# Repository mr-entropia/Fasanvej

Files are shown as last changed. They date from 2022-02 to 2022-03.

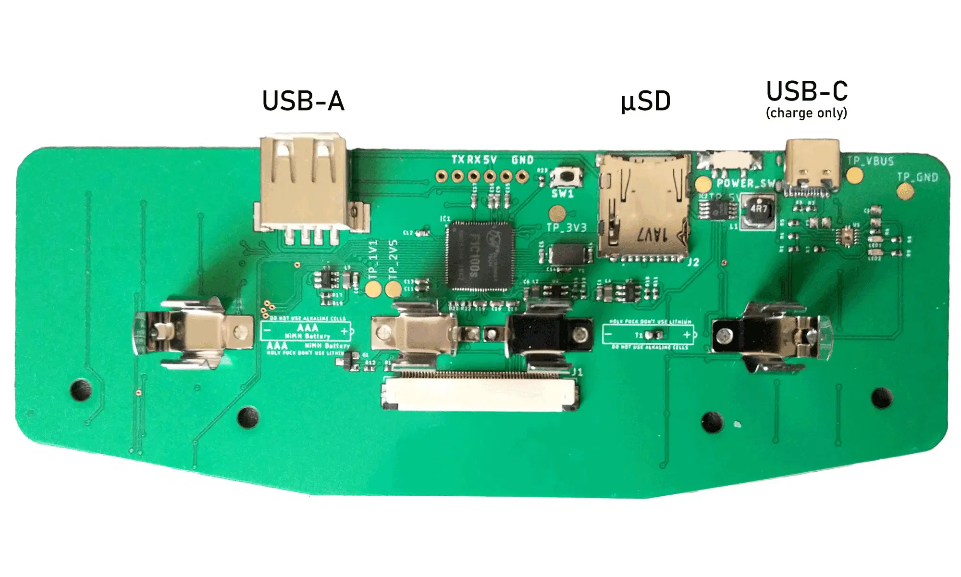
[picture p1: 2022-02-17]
Reference material/Allwinner-FC100s-minimal-viable-computer-board.webp

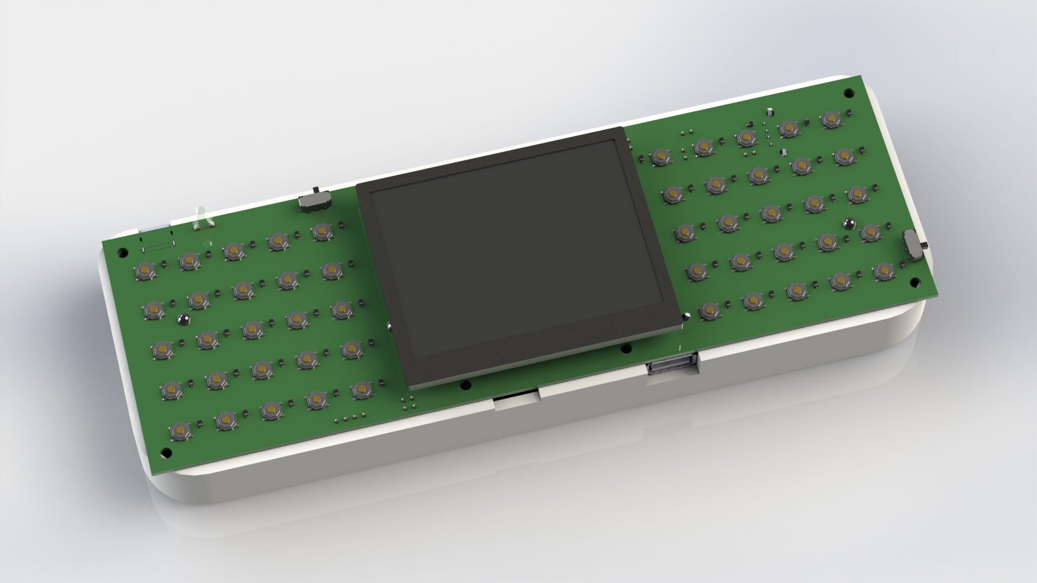
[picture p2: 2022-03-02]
render1_without_top.jpg

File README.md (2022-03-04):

# Fasanvej
A hand-held Linux computer, inspired by Brian Benchoff's similar project

## Features
- Allwinner F1C200s SoC, an ARM926EJ-S running at 500 MHz
- 64 MB DDR DRAM, embedded in the SoC
- 3.2" TFT LCD, 320x240 resolution
- QWERTY keyboard (implemented using a SAMD21 MCU, connects via USB)
- Game mode switch which alters key mapping
- USB hub with one external USB A connector
- Internal USB A type connector for a miniature WiFi adapter
- Mono speaker
- microSD slot
- SPI NOR FLASH
- Powered by 2P1S 18650 li-ion battery
- Built-in charger using a USB C type connector
- High efficiency DC-DC converters to power everything

## Task list
- [x] Finalize schematics
- [x] Place components on PCB
- [ ] Route PCB
- [x] Design a 3D-printable enclosure
- [ ] Source parts
- [ ] Build prototype
- [ ] Make software work
- [ ] Play DOOM

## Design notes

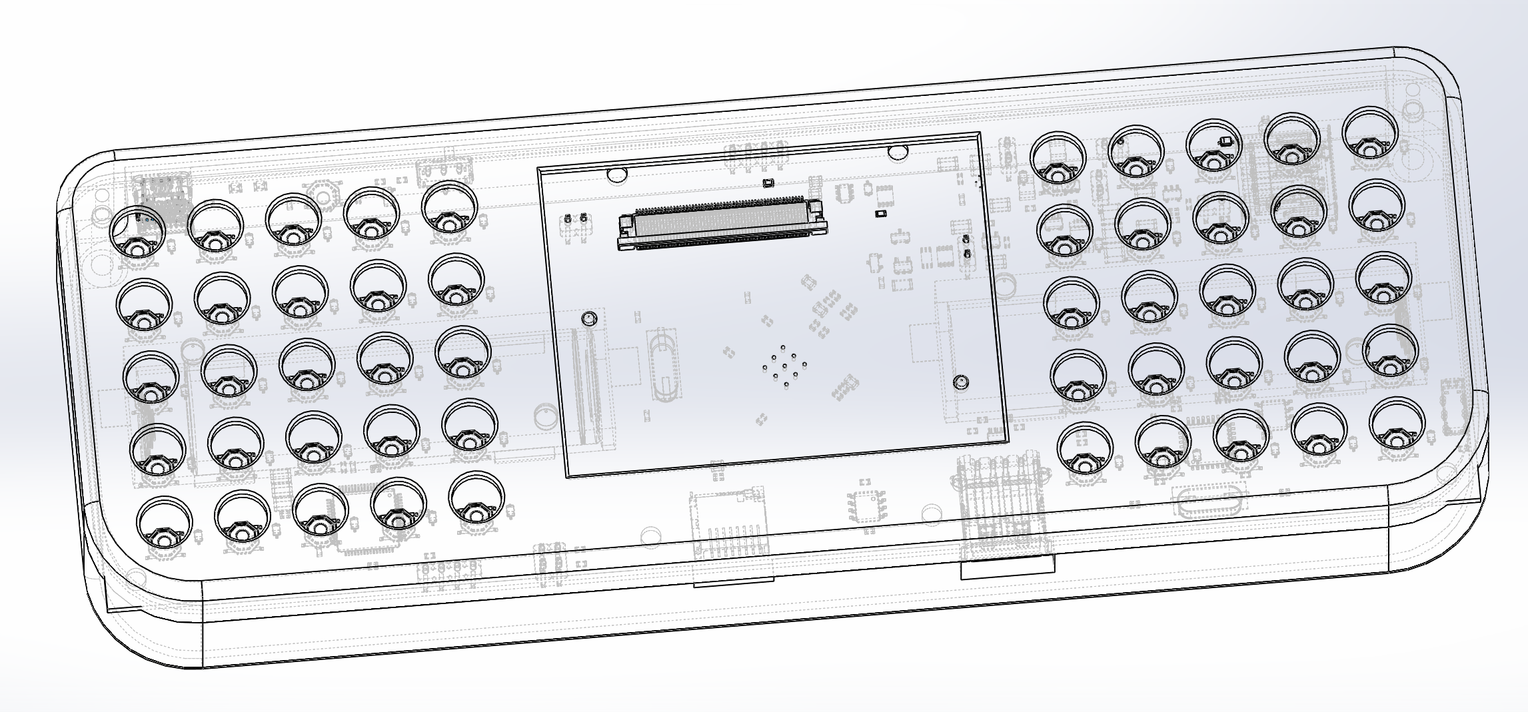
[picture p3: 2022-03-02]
Mech preview.png

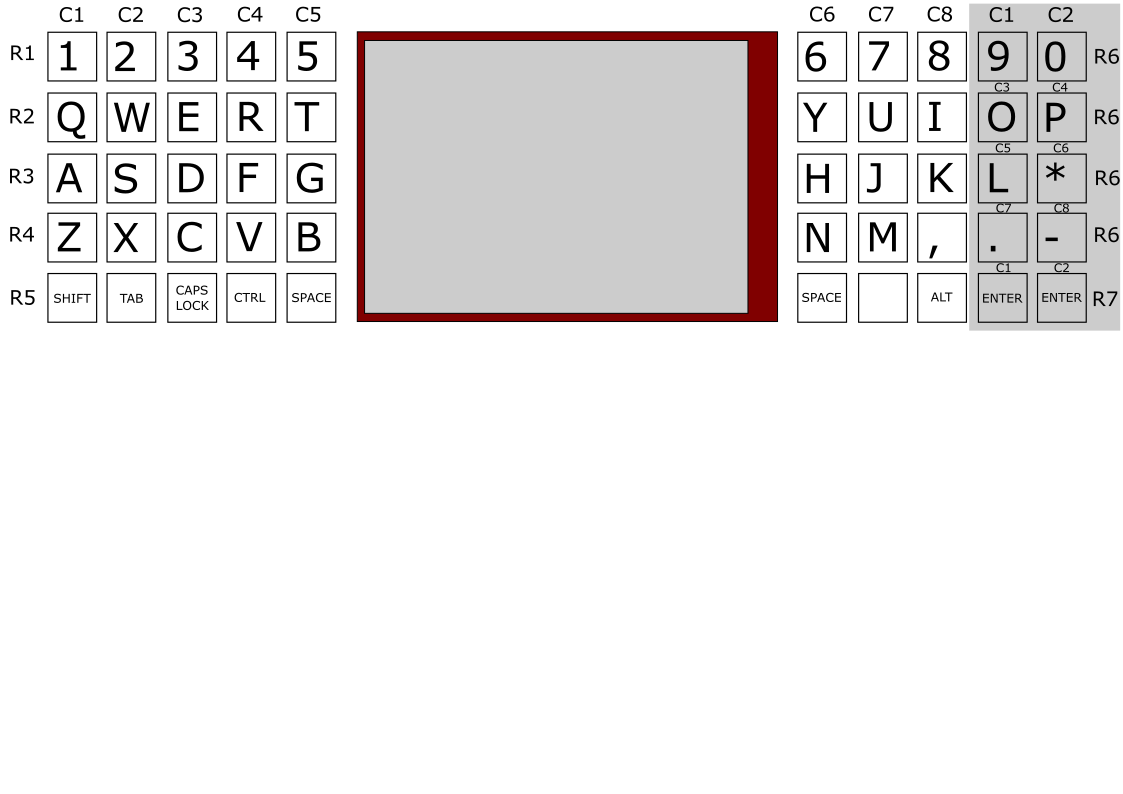
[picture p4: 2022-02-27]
Keymap.png

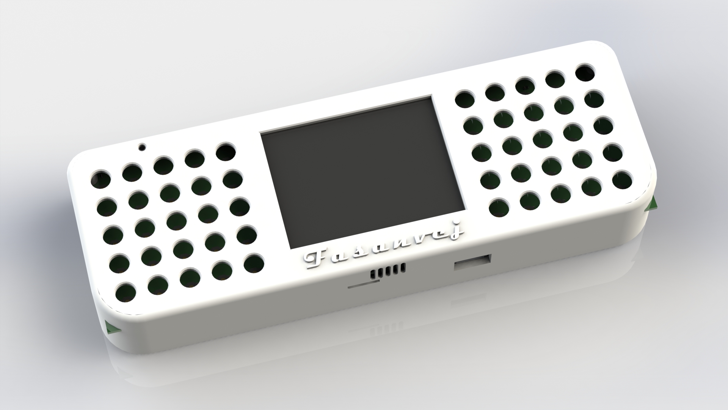
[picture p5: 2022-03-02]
render1.jpg

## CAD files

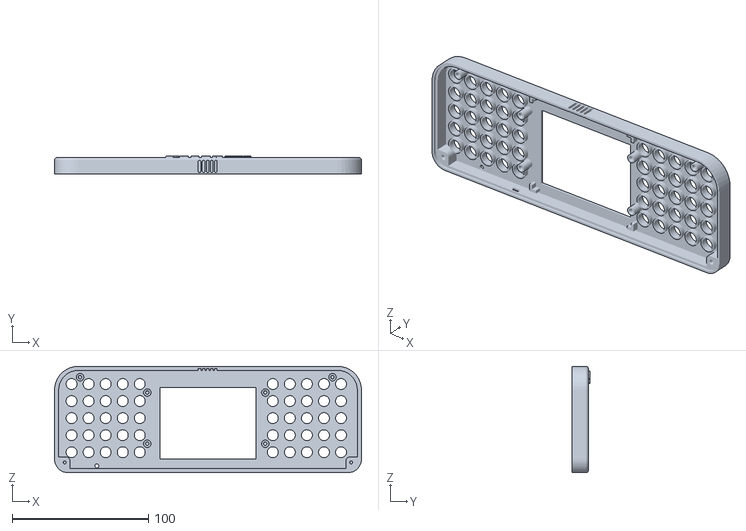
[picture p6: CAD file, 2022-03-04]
Mechanical/Case top.STL
225.0 x 13.0 x 78.0

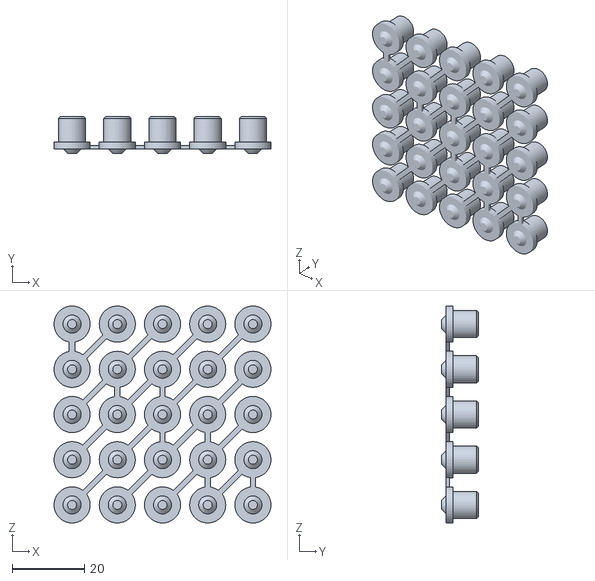
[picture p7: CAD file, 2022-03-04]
Mechanical/5x5 keymap.STL
60.0 x 10.2 x 60.0

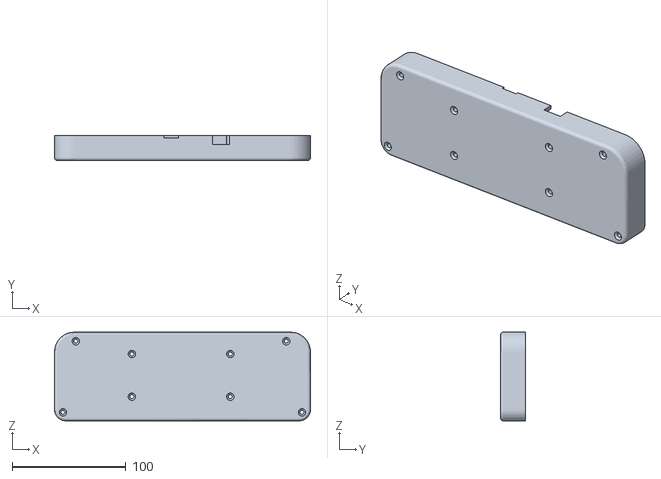
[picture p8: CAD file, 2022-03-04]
Mechanical/Case bottom.STL
225.0 x 22.0 x 78.0

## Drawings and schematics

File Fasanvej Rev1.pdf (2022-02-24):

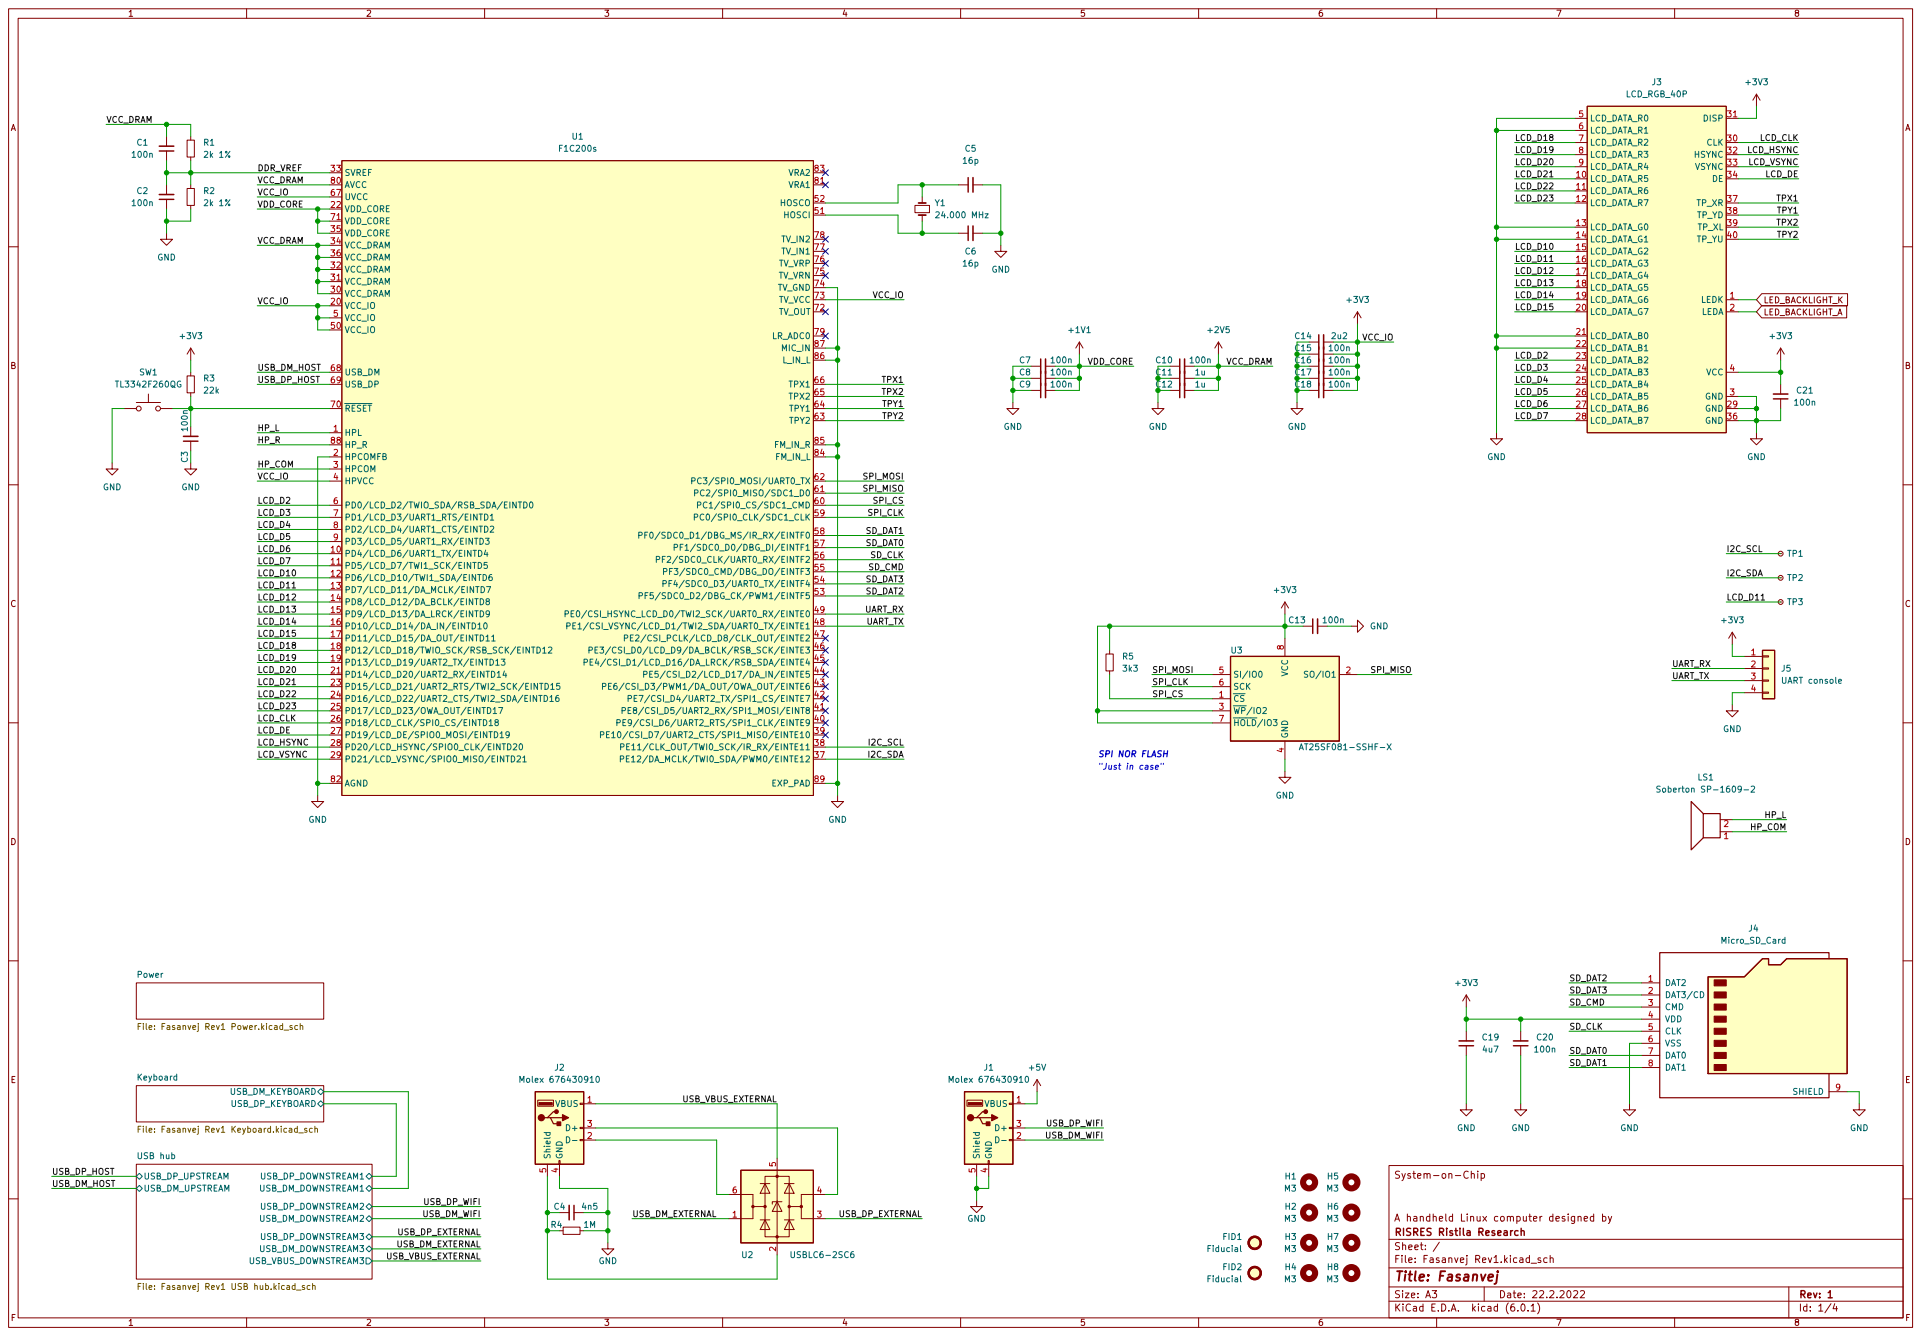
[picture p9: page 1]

4 SI/IO0 5 SCK 6 ~{HOLD}/IO3 7 VCC

"Just in case" SPI NOR FLASH

USB_DP_DOWNSTREAM3 USB_DP_DOWNSTREAM1 USB_DM_DOWNSTREAM1 USB_DM_DOWNSTREAM2 USB_DP_DOWNSTREAM2 USB_DM_DOWNSTREAM3 USB_VBUS_DOWNSTREAM3 USB hub File: Fasanvej Rev1 USB hub.kicad_sch Power File: Fasanvej Rev1 Power.kicad_sch

File: Fasanvej Rev1.kicad_sch Sheet: / RISRES Ristila Research A handheld Linux computer designed by

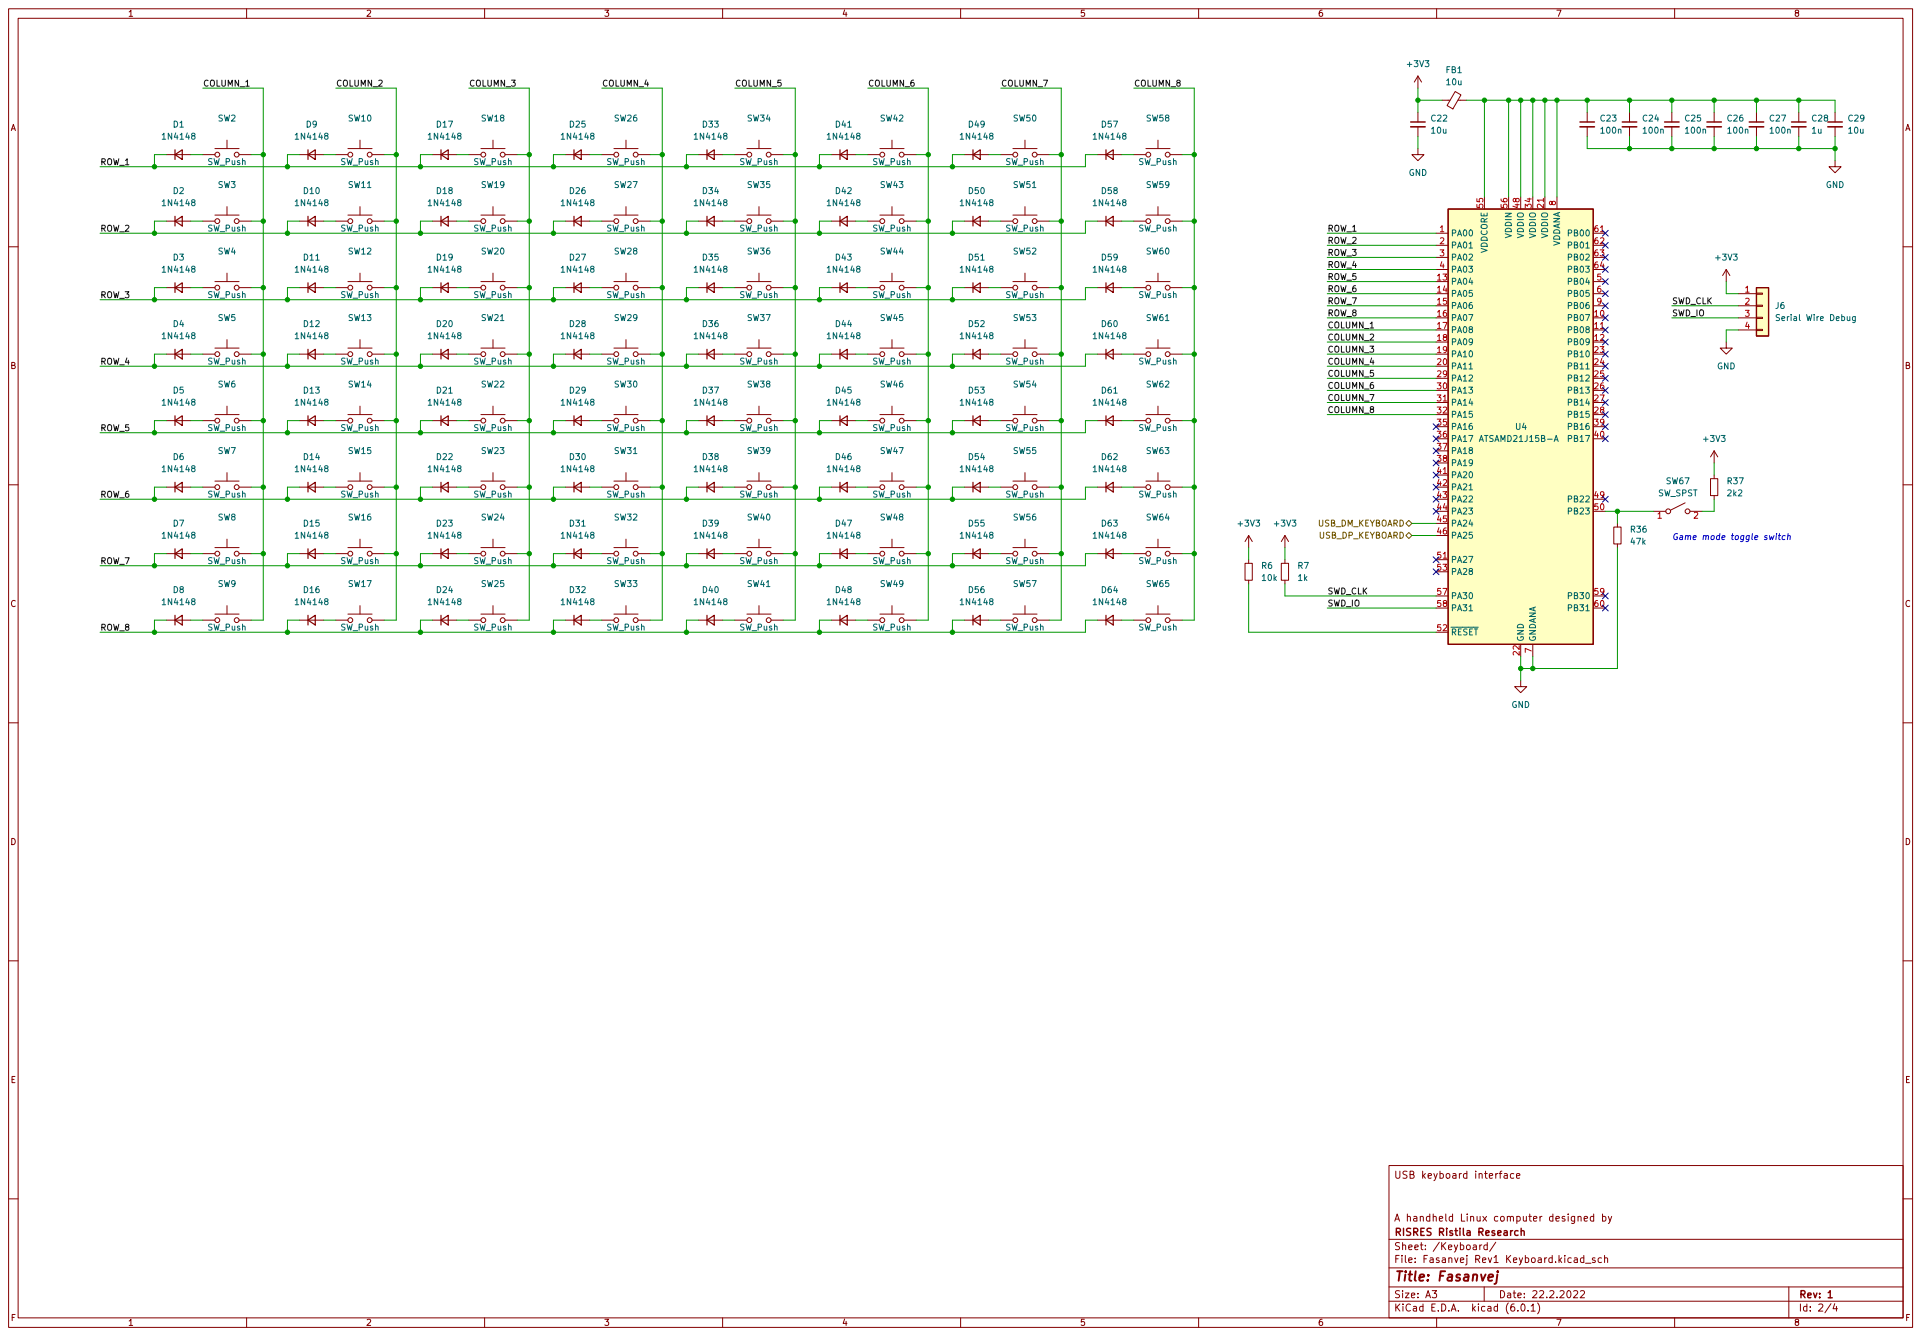
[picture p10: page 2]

Sheet: /Keyboard/ RISRES Ristila Research A handheld Linux computer designed by

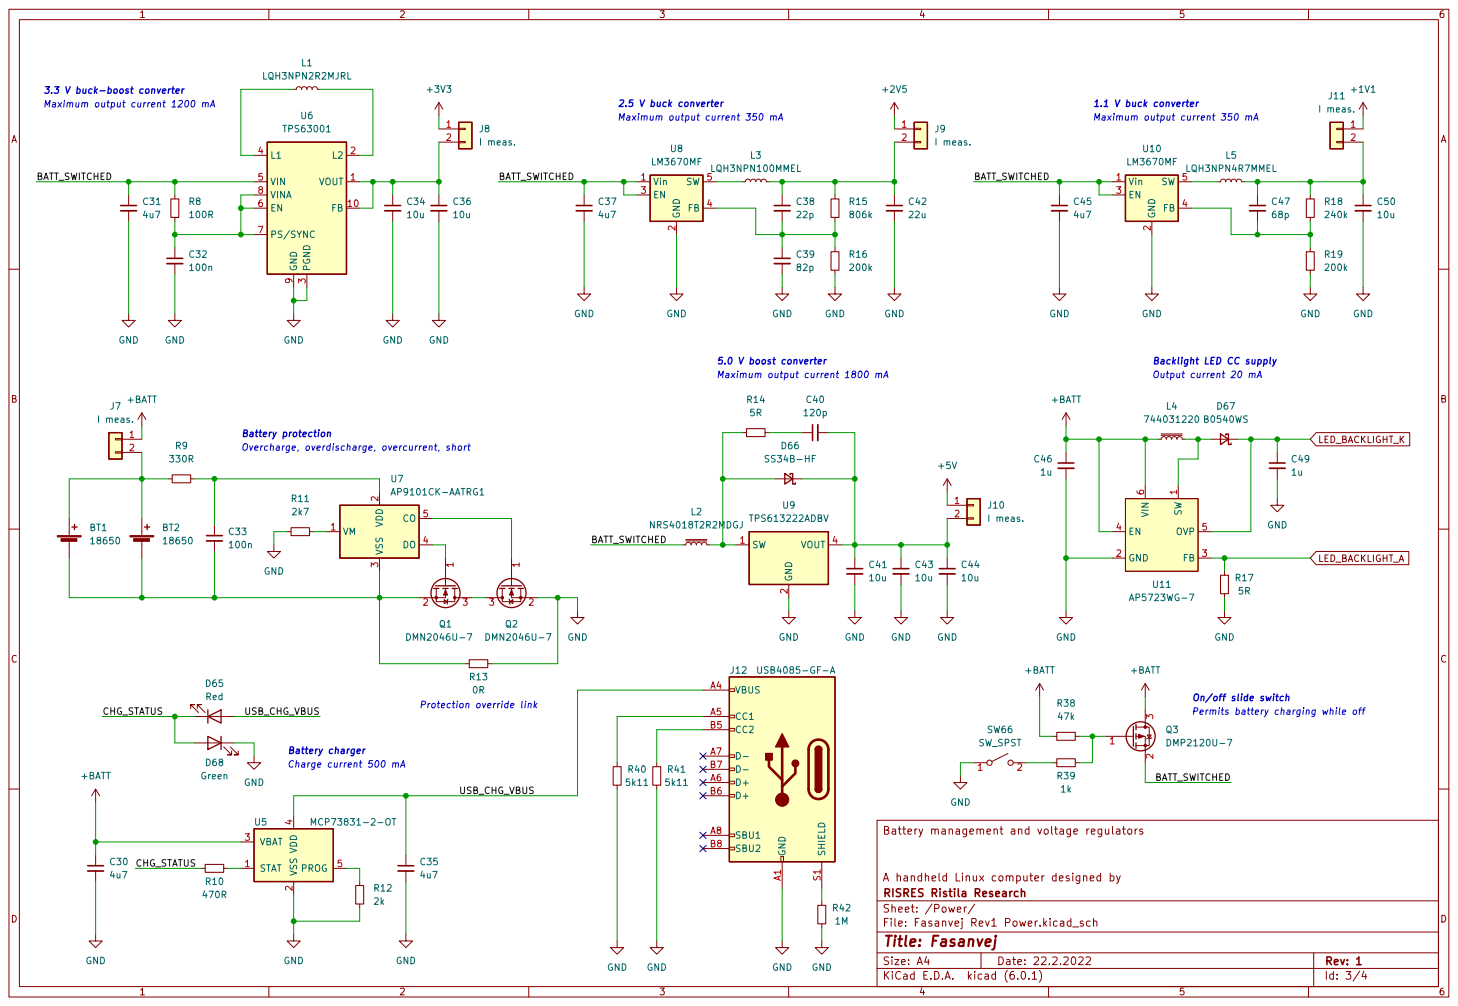
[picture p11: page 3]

Maximum output current 1200 mA

1.1 V buck converter On/off slide switch Permits battery charging while off
Maximum output current 350 mA

2.5 V buck converter

5.0 V boost converter Maximum output current 1800 mA

Backlight LED CC supply
Output current 20 mA

Battery protection
Overcharge, overdischarge, overcurrent, short

1 GND 2 FB 3 EN 4 OVP 5 VIN

Battery management and voltage regulators GND

File: Fasanvej Rev1 Power.kicad_sch Sheet: /Power/ RISRES Ristila Research A handheld Linux computer designed by

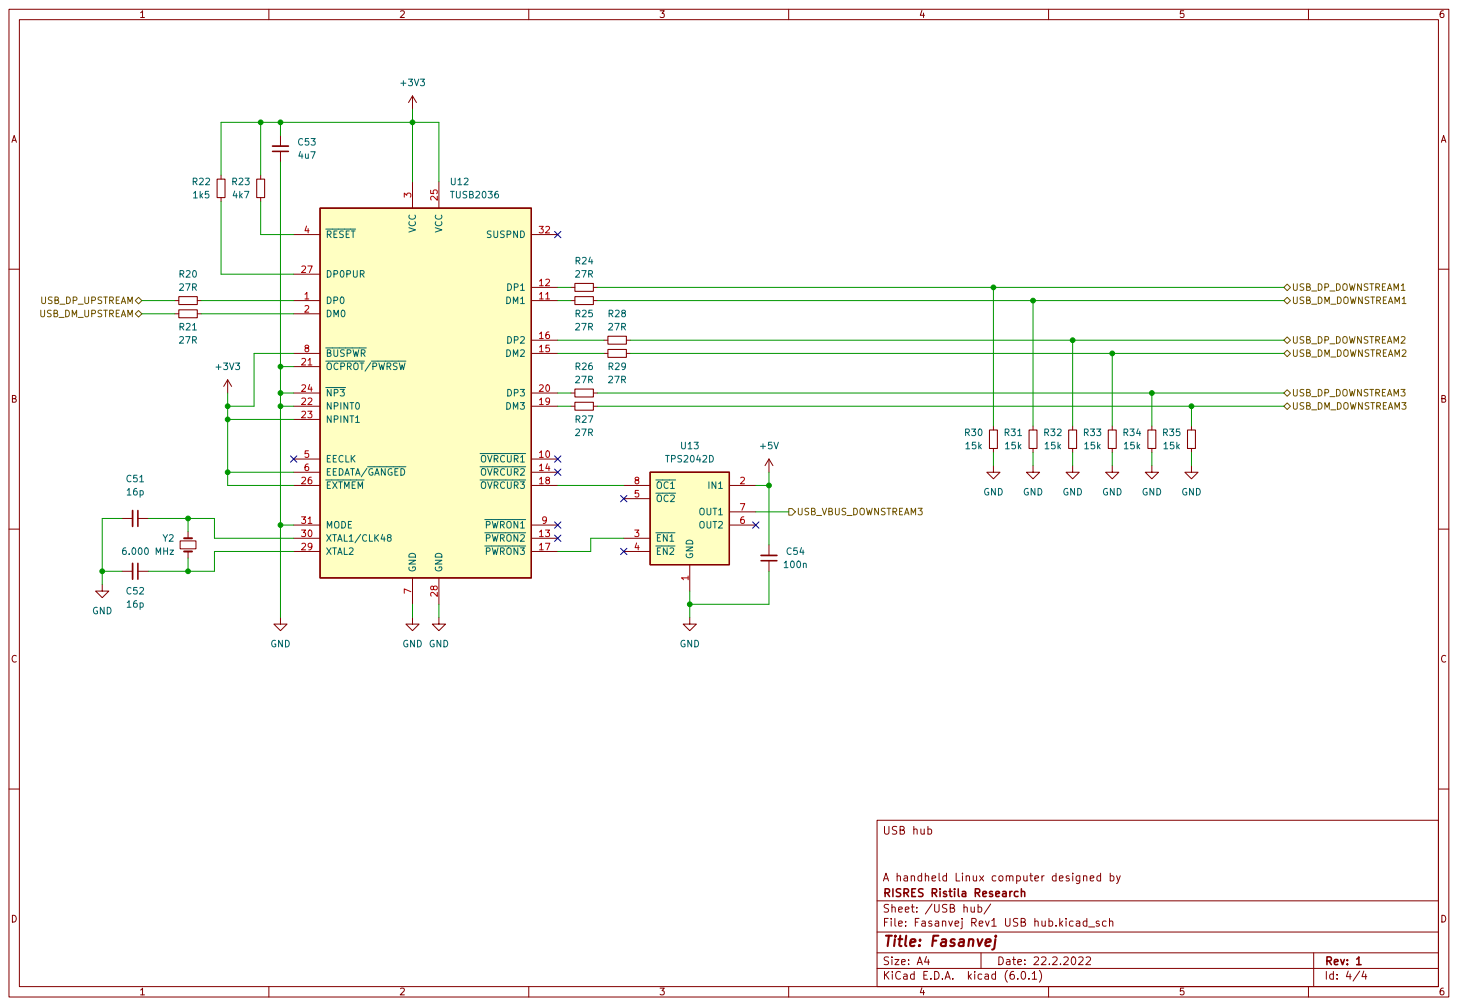
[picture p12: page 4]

3 XTAL1/CLK48 30 MODE 31 SUSPND 32 ~{RESET} 4 EECLK 5 EEDATA/~{GANGED} 6 GND

File: Fasanvej Rev1 USB hub.kicad_sch Sheet: /USB hub/ RISRES Ristila Research A handheld Linux computer designed by USB hub GND

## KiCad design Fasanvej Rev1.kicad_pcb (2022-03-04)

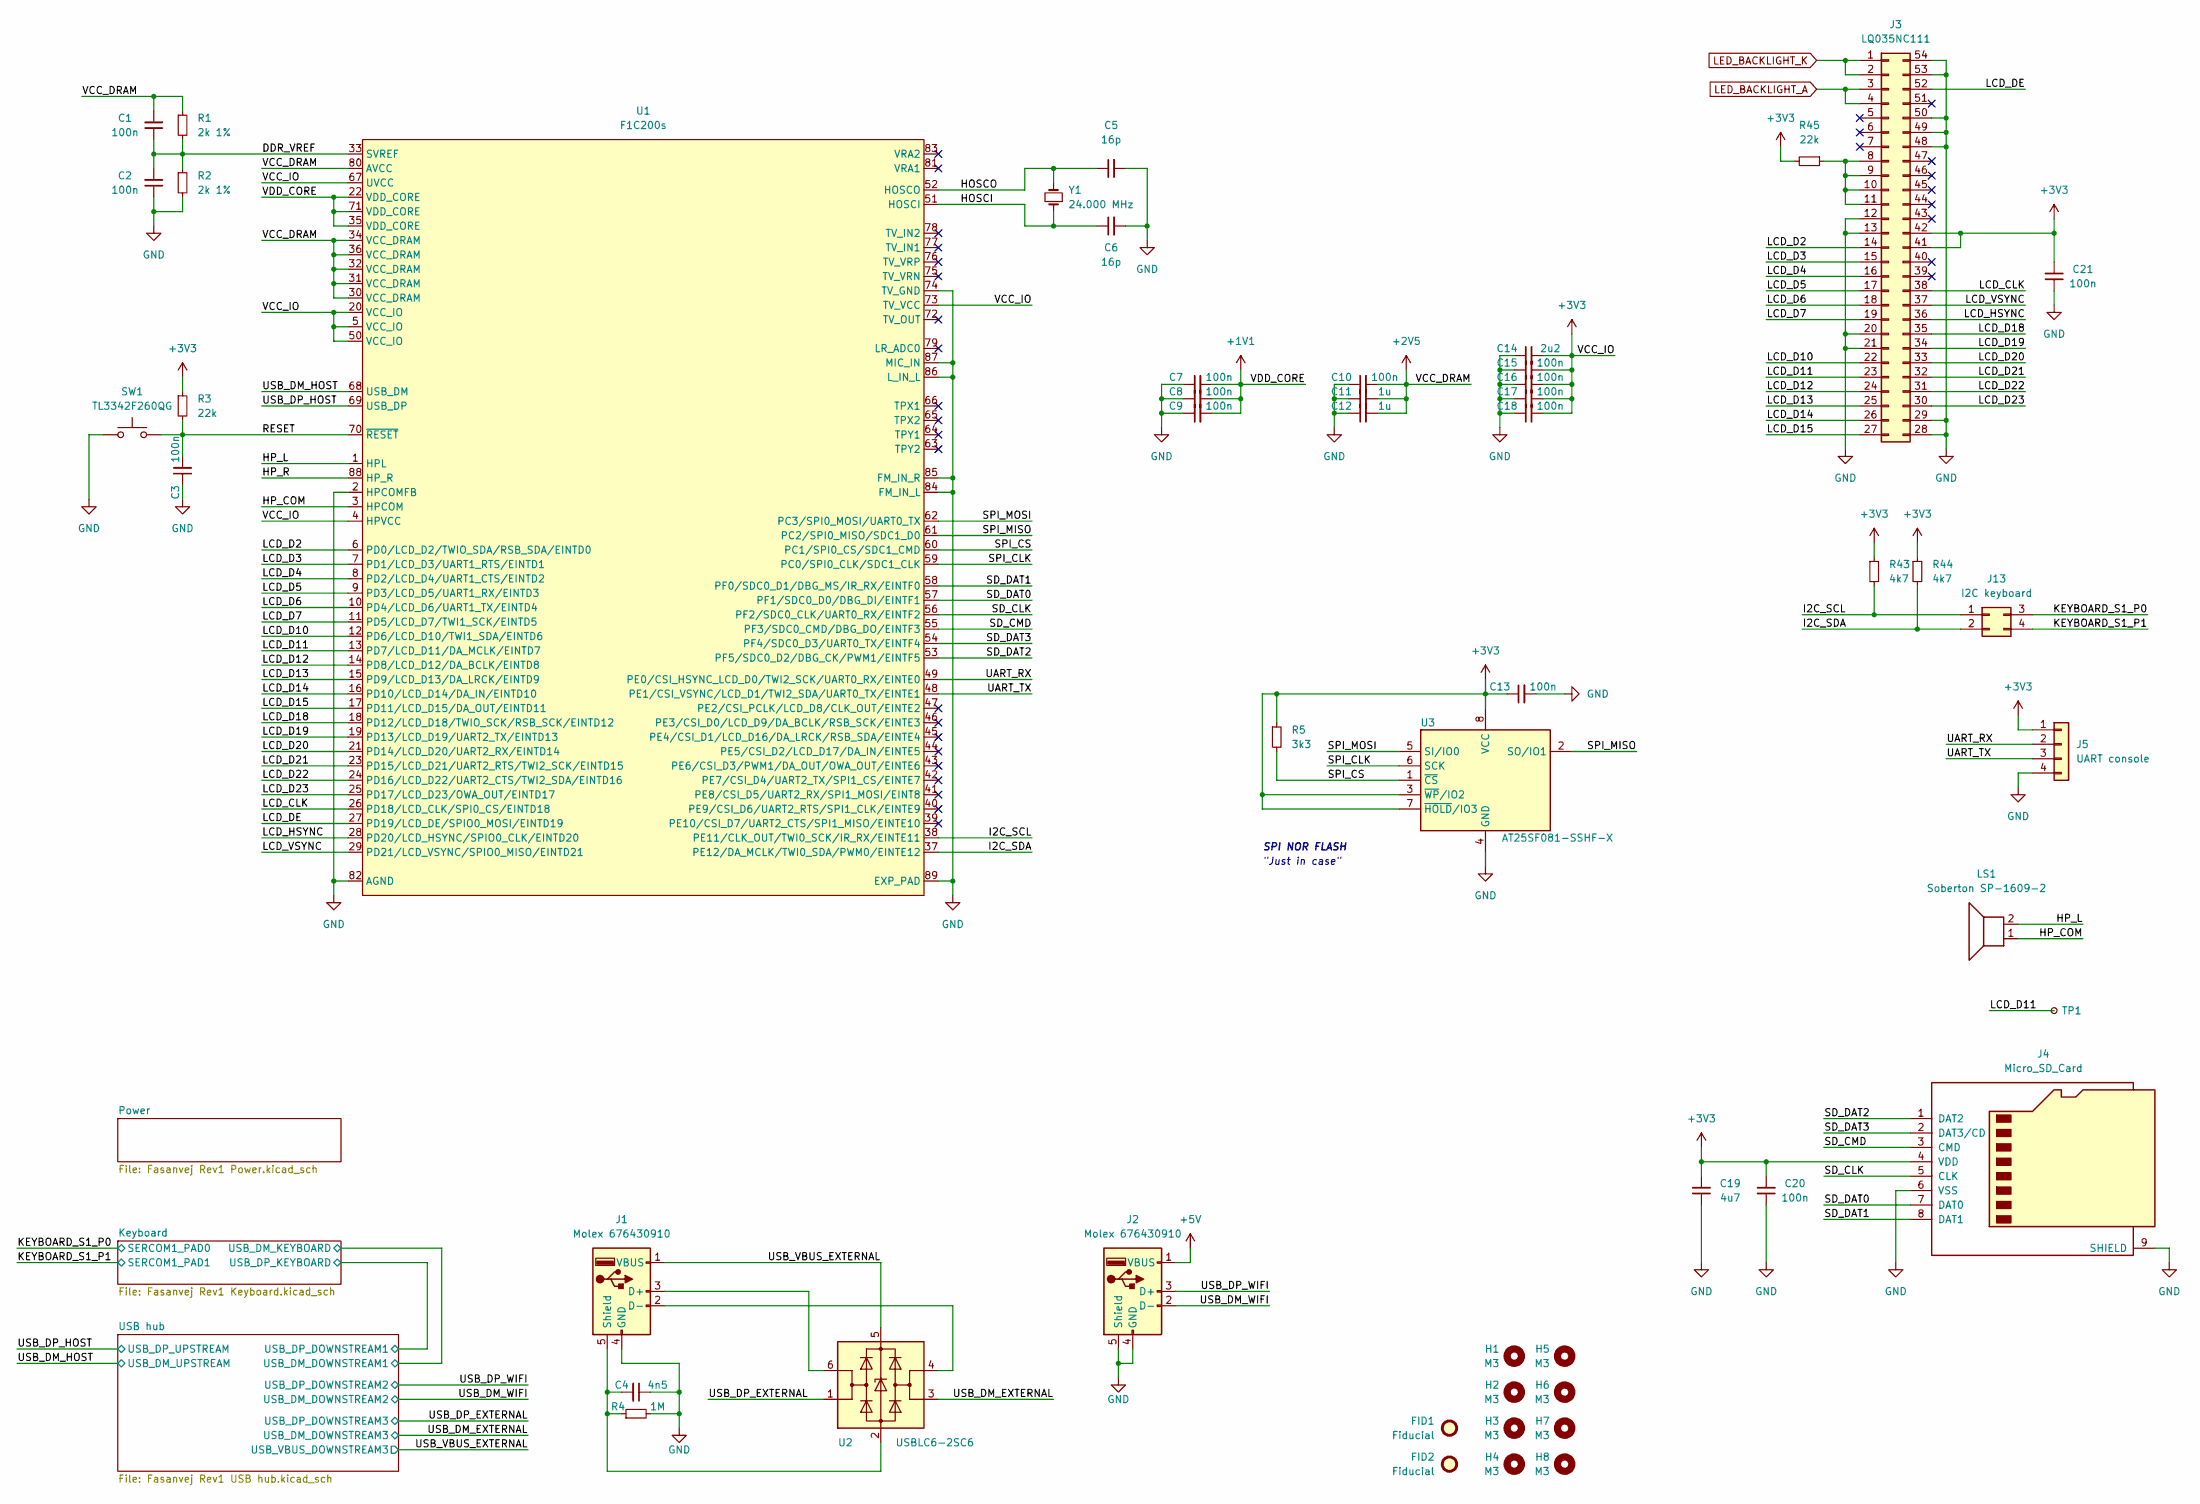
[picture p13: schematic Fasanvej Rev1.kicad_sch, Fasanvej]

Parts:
C1, C2, C3, C7, C8, C9, C10, C13, C15, C16, C17, C18, C20, C21: 100n; C_0603_1608Metric_Pad1.08x0.95mm_HandSolder
C4: 4n5; C_0603_1608Metric_Pad1.08x0.95mm_HandSolder
C5, C6: 16p; C_0603_1608Metric_Pad1.08x0.95mm_HandSolder
C11, C12: 1u; C_0805_2012Metric_Pad1.18x1.45mm_HandSolder
C14: 2u2; C_0805_2012Metric_Pad1.18x1.45mm_HandSolder
C19: 4u7; C_0805_2012Metric_Pad1.18x1.45mm_HandSolder
FID1, FID2: Fiducial; Fiducial_1.5mm_Mask3mm
H1, H2, H3, H4, H5, H6, H7, H8: M3; MountingHole_3.2mm_M3
J1, J2: Molex 676430910; USB_A_Molex_67643_Horizontal
J3: LQ035NC111; FFC2B22-54-T
J4: Micro_SD_Card; microSD_HC_Hirose_DM3D-SF
J5: UART console; PinHeader_1x04_P2.54mm_Vertical
J13: I2C keyboard; PinHeader_2x02_P2.54mm_Vertical
LS1: Soberton SP-1609-2; PinHeader_1x02_P2.54mm_Vertical
R1, R2: 2k 1%; R_0603_1608Metric_Pad0.98x0.95mm_HandSolder
R3, R45: 22k; R_0603_1608Metric_Pad0.98x0.95mm_HandSolder
R4: 1M; R_0603_1608Metric_Pad0.98x0.95mm_HandSolder
R5: 3k3; R_0603_1608Metric_Pad0.98x0.95mm_HandSolder
R43, R44: 4k7; R_0603_1608Metric_Pad0.98x0.95mm_HandSolder
SW1: TL3342F260QG; SW_SPST_TL3342
TP1: TestPoint_Small; TestPoint_Pad_D2.5mm
U1: F1C200s; QFN-88_EP_10x10_Pitch0.4mm
U2: USBLC6-2SC6; SOT-23-6
U3: AT25SF081-SSHF-X; SOIC-8_3.9x4.9mm_P1.27mm
Y1: 24.000 MHz; Crystal_SMD_HC49-SD_HandSoldering

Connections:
+1V1: C7.2, C8.2, C9.2, U1.22 (VDD_CORE), U1.35 (VDD_CORE), U1.71 (VDD_CORE); also elsewhere on the board
+2V5: C1.2, C10.2, C11.2, C12.2, R1.1, U1.30 (VCC_DRAM), U1.31 (VCC_DRAM), U1.32 (VCC_DRAM), U1.34 (VCC_DRAM), U1.36 (VCC_DRAM), U1.80 (AVCC); also elsewhere on the board
+3V3: C13.1, C14.2, C15.2, C16.2, C17.2, C18.2, C19.2, C20.2, C21.2, J3.41, J3.42, J4.4 (VDD), J5.1, R3.1, R5.1, R43.1, R44.1, R45.2, U1.4 (HPVCC), U1.5 (VCC_IO), U1.20 (VCC_IO), U1.50 (VCC_IO), U1.67 (UVCC), U1.73 (TV_VCC), U3.3 (~WP/IO2), U3.7 (~HOLD/IO3), U3.8 (VCC); also elsewhere on the board
+5V: J2.1 (VBUS); also elsewhere on the board
/DDR_VREF: C1.1, C2.2, R1.2, R2.1, U1.33 (SVREF)
/HOSCI: C6.1, U1.51 (HOSCI), Y1.1
/HOSCO: C5.1, U1.52 (HOSCO), Y1.2
/HP_COM: LS1.1, U1.3 (HPCOM)
/HP_L: LS1.2, U1.1 (HPL)
/HP_R: U1.88 (HP_R)
/I2C_SCL: J13.1, R43.2, U1.38 (PE11/CLK_OUT/TWI0_SCK/IR_RX/EINTE11)
/I2C_SDA: J13.2, R44.2, U1.37 (PE12/DA_MCLK/TWI0_SDA/PWM0/EINTE12)
/KEYBOARD_S1_P0: J13.3; also elsewhere on the board
/KEYBOARD_S1_P1: J13.4; also elsewhere on the board
/LCD_CLK: J3.38, U1.26 (PD18/LCD_CLK/SPI0_CS/EINTD18)
/LCD_D2: J3.14, U1.6 (PD0/LCD_D2/TWIO_SDA/RSB_SDA/EINTD0)
/LCD_D3: J3.15, U1.7 (PD1/LCD_D3/UART1_RTS/EINTD1)
/LCD_D4: J3.16, U1.8 (PD2/LCD_D4/UART1_CTS/EINTD2)
/LCD_D5: J3.17, U1.9 (PD3/LCD_D5/UART1_RX/EINTD3)
/LCD_D6: J3.18, U1.10 (PD4/LCD_D6/UART1_TX/EINTD4)
/LCD_D7: J3.19, U1.11 (PD5/LCD_D7/TWI1_SCK/EINTD5)
/LCD_D10: J3.22, U1.12 (PD6/LCD_D10/TWI1_SDA/EINTD6)
/LCD_D11: J3.23, TP1.1, U1.13 (PD7/LCD_D11/DA_MCLK/EINTD7)
/LCD_D12: J3.24, U1.14 (PD8/LCD_D12/DA_BCLK/EINTD8)
/LCD_D13: J3.25, U1.15 (PD9/LCD_D13/DA_LRCK/EINTD9)
/LCD_D14: J3.26, U1.16 (PD10/LCD_D14/DA_IN/EINTD10)
/LCD_D15: J3.27, U1.17 (PD11/LCD_D15/DA_OUT/EINTD11)
/LCD_D18: J3.35, U1.18 (PD12/LCD_D18/TWIO_SCK/RSB_SCK/EINTD12)
/LCD_D19: J3.34, U1.19 (PD13/LCD_D19/UART2_TX/EINTD13)
/LCD_D20: J3.33, U1.21 (PD14/LCD_D20/UART2_RX/EINTD14)
/LCD_D21: J3.32, U1.23 (PD15/LCD_D21/UART2_RTS/TWI2_SCK/EINTD15)
/LCD_D22: J3.31, U1.24 (PD16/LCD_D22/UART2_CTS/TWI2_SDA/EINTD16)
/LCD_D23: J3.30, U1.25 (PD17/LCD_D23/OWA_OUT/EINTD17)
/LCD_DE: J3.52, U1.27 (PD19/LCD_DE/SPIO0_MOSI/EINTD19)
/LCD_HSYNC: J3.36, U1.28 (PD20/LCD_HSYNC/SPIO0_CLK/EINTD20)
/LCD_VSYNC: J3.37, U1.29 (PD21/LCD_VSYNC/SPIO0_MISO/EINTD21)
/RESET: C3.2, R3.2, SW1.2, U1.70 (~RESET)
/SD_CLK: J4.5 (CLK), U1.56 (PF2/SDC0_CLK/UART0_RX/EINTF2)
/SD_CMD: J4.3 (CMD), U1.55 (PF3/SDC0_CMD/DBG_DO/EINTF3)
/SD_DAT0: J4.7 (DAT0), U1.57 (PF1/SDC0_D0/DBG_DI/EINTF1)
/SD_DAT1: J4.8 (DAT1), U1.58 (PF0/SDC0_D1/DBG_MS/IR_RX/EINTF0)
/SD_DAT2: J4.1 (DAT2), U1.53 (PF5/SDC0_D2/DBG_CK/PWM1/EINTF5)
/SD_DAT3: J4.2 (DAT3/CD), U1.54 (PF4/SDC0_D3/UART0_TX/EINTF4)
/SPI_CLK: U1.59 (PC0/SPI0_CLK/SDC1_CLK), U3.6 (SCK)
/SPI_CS: R5.2, U1.60 (PC1/SPI0_CS/SDC1_CMD), U3.1 (~CS)
/SPI_MISO: U1.61 (PC2/SPI0_MISO/SDC1_D0), U3.2 (SO/IO1)
/SPI_MOSI: U1.62 (PC3/SPI0_MOSI/UART0_TX), U3.5 (SI/IO0)
/UART_RX: J5.2, U1.49 (PE0/CSI_HSYNC_LCD_D0/TWI2_SCK/UART0_RX/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)
/UART_TX: J5.3, U1.48 (PE1/CSI_VSYNC/LCD_D1/TWI2_SDA/UART0_TX/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)
/USB_DM_EXTERNAL: U2.3 (I/O2); also elsewhere on the board
/USB_DM_HOST: U1.68 (USB_DM); also elsewhere on the board
/USB_DM_WIFI: J2.2 (D-); also elsewhere on the board
/USB_DP_EXTERNAL: U2.1 (I/O1); also elsewhere on the board
/USB_DP_HOST: U1.69 (USB_DP); also elsewhere on the board
/USB_DP_WIFI: J2.3 (D+); also elsewhere on the board
/USB_VBUS_EXTERNAL: J1.1 (VBUS), U2.5 (VBUS); also elsewhere on the board
GND: C2.1, C3.1, C4.1, C5.2, C6.2, C7.1, C8.1, C9.1, C10.1, C11.1, C12.1, C13.2, C14.1, C15.1, C16.1, C17.1, C18.1, C19.1, C20.1, C21.1, J1.4 (GND), J2.4 (GND), J2.5 (Shield), J3.12, J3.13, J3.20, J3.21, J3.28, J3.29, J3.48, J3.49, J3.50, J3.53, J3.54, J4.6 (VSS), J4.9 (SHIELD), J5.4, R2.2, R4.2, SW1.1, U1.2 (HPCOMFB), U1.74 (TV_GND), U1.82 (AGND), U1.84 (FM_IN_L), U1.85 (FM_IN_R), U1.86 (L_IN_L), U1.87 (MIC_IN), U1.89 (EXP_PAD), U3.4 (GND); also elsewhere on the board
LED_BACKLIGHT_A: J3.3, J3.4; also elsewhere on the board
LED_BACKLIGHT_K: J3.1, J3.2; also elsewhere on the board
unnamed: C4.2, J1.5 (Shield), R4.1, U2.2 (GND)
unnamed: J1.2 (D-), U2.4 (I/O2)
unnamed: J1.3 (D+), U2.6 (I/O1)
unnamed: J3.8, J3.9, J3.10, J3.11, R45.1

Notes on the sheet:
SPI NOR FLASH
"Just in case"

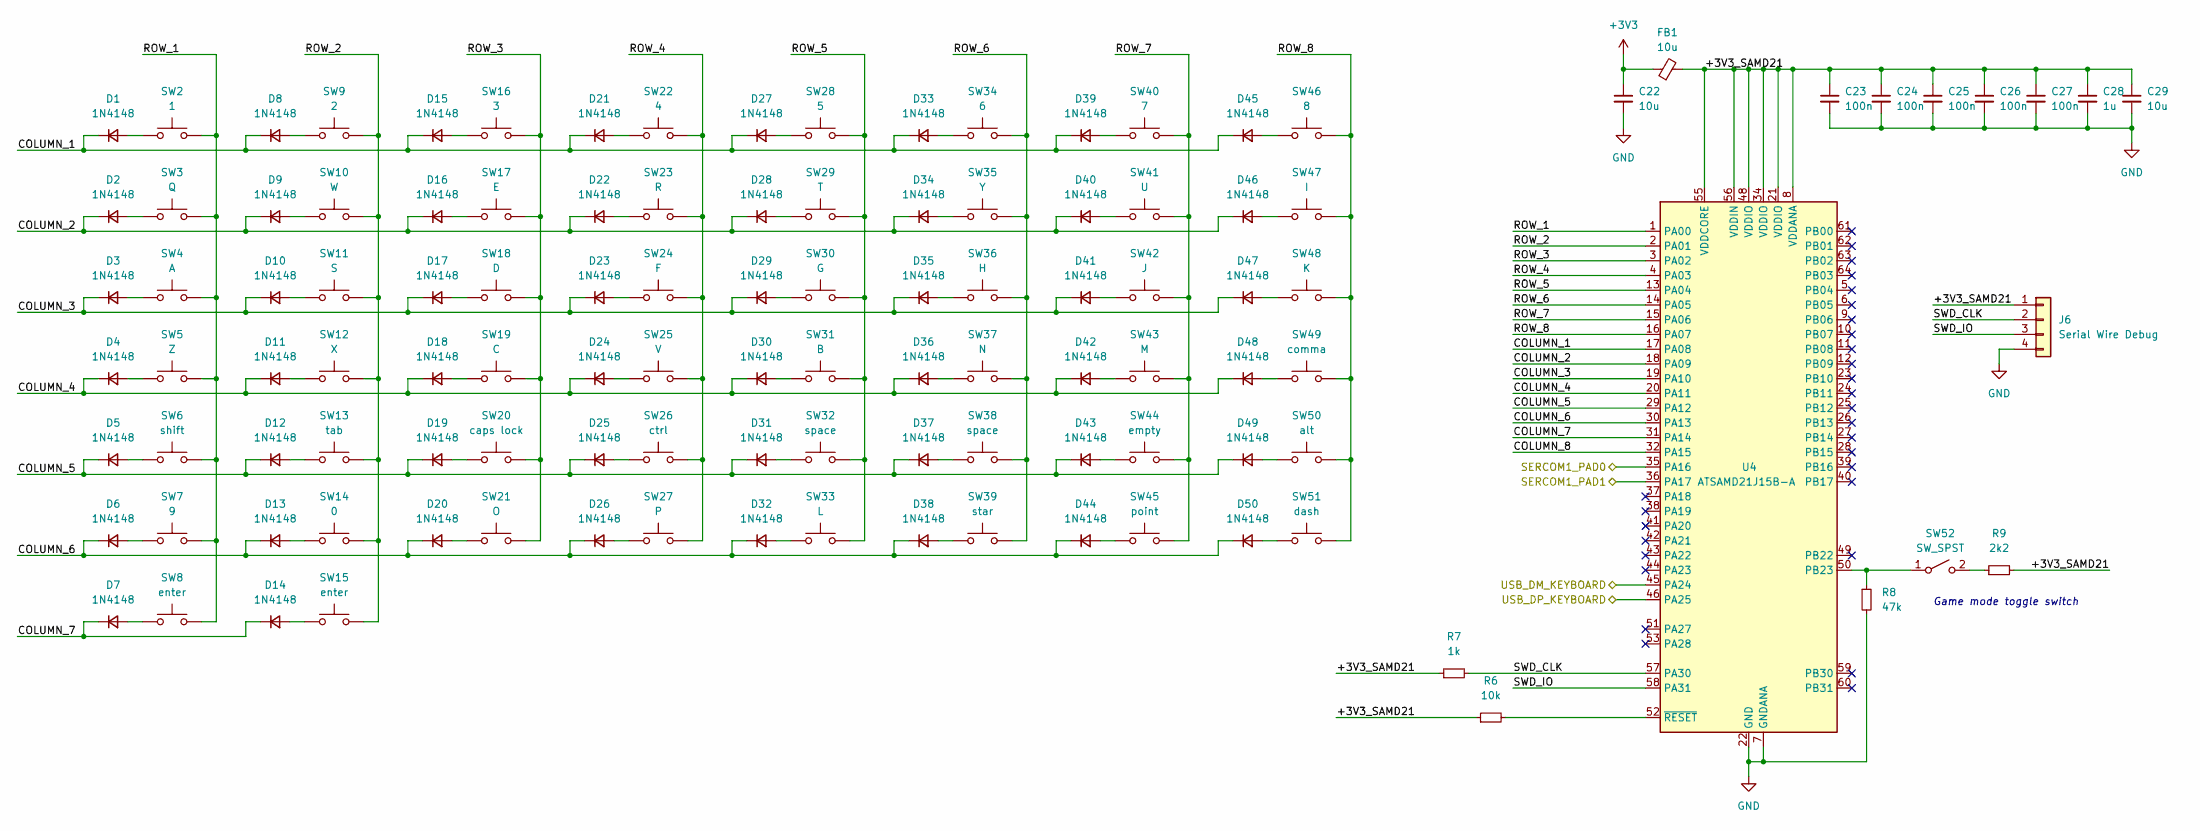
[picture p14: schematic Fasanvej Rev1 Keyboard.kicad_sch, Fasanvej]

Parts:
C22, C29: 10u; C_1206_3216Metric_Pad1.33x1.80mm_HandSolder
C23, C24, C25, C26, C27: 100n; C_0603_1608Metric_Pad1.08x0.95mm_HandSolder
C28: 1u; C_0603_1608Metric_Pad1.08x0.95mm_HandSolder
D1, D2, D3, D4, D5, D6, D7, D8, D9, D10, D11, D12, D13, D14, D15, D16, D17, D18, D19, D20, D21, D22, D23, D24, D25, D26, D27, D28, D29, D30, D31, D32, D33, D34, D35, D36, D37, D38, D39, D40, D41, D42, D43, D44, D45, D46, D47, D48, D49, D50: 1N4148; D_SOD-323_HandSoldering
FB1: 10u; L_1206_3216Metric_Pad1.22x1.90mm_HandSolder
J6: Serial Wire Debug; PinHeader_1x04_P2.54mm_Vertical
R6: 10k; R_0603_1608Metric_Pad0.98x0.95mm_HandSolder
R7: 1k; R_0603_1608Metric_Pad0.98x0.95mm_HandSolder
R8: 47k; R_0603_1608Metric_Pad0.98x0.95mm_HandSolder
R9: 2k2; R_0603_1608Metric_Pad0.98x0.95mm_HandSolder
SW2: 1; SW_SPST_TL3342
SW3: Q; SW_SPST_TL3342
SW4: A; SW_SPST_TL3342
SW5: Z; SW_SPST_TL3342
SW6: shift; SW_SPST_TL3342
SW7: 9; SW_SPST_TL3342
SW8, SW15: enter; SW_SPST_TL3342
SW9: 2; SW_SPST_TL3342
SW10: W; SW_SPST_TL3342
SW11: S; SW_SPST_TL3342
SW12: X; SW_SPST_TL3342
SW13: tab; SW_SPST_TL3342
SW14: 0; SW_SPST_TL3342
SW16: 3; SW_SPST_TL3342
SW17: E; SW_SPST_TL3342
SW18: D; SW_SPST_TL3342
SW19: C; SW_SPST_TL3342
SW20: caps lock; SW_SPST_TL3342
SW21: O; SW_SPST_TL3342
SW22: 4; SW_SPST_TL3342
SW23: R; SW_SPST_TL3342
SW24: F; SW_SPST_TL3342
SW25: V; SW_SPST_TL3342
SW26: ctrl; SW_SPST_TL3342
SW27: P; SW_SPST_TL3342
SW28: 5; SW_SPST_TL3342
SW29: T; SW_SPST_TL3342
SW30: G; SW_SPST_TL3342
SW31: B; SW_SPST_TL3342
SW32, SW38: space; SW_SPST_TL3342
SW33: L; SW_SPST_TL3342
SW34: 6; SW_SPST_TL3342
SW35: Y; SW_SPST_TL3342
SW36: H; SW_SPST_TL3342
SW37: N; SW_SPST_TL3342
SW39: star; SW_SPST_TL3342
SW40: 7; SW_SPST_TL3342
SW41: U; SW_SPST_TL3342
SW42: J; SW_SPST_TL3342
SW43: M; SW_SPST_TL3342
SW44: empty; SW_SPST_TL3342
SW45: point; SW_SPST_TL3342
SW46: 8; SW_SPST_TL3342
SW47: I; SW_SPST_TL3342
SW48: K; SW_SPST_TL3342
SW49: comma; SW_SPST_TL3342
SW50: alt; SW_SPST_TL3342
SW51: dash; SW_SPST_TL3342
SW52: SW_SPST; SW_CuK_JS202011AQN_DPDT_Angled
U4: ATSAMD21J15B-A; TQFP-64_10x10mm_P0.5mm

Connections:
+3V3: C22.1, FB1.1; also elsewhere on the board
/KEYBOARD_S1_P0: U4.35 (PA16); also elsewhere on the board
/KEYBOARD_S1_P1: U4.36 (PA17); also elsewhere on the board
/Keyboard/+3V3_SAMD21: C23.1, C24.1, C25.1, C26.1, C27.1, C28.1, C29.1, FB1.2, J6.1, R6.1, R7.1, R9.2, U4.8 (VDDANA), U4.21 (VDDIO), U4.34 (VDDIO), U4.48 (VDDIO), U4.55 (VDDCORE), U4.56 (VDDIN)
/Keyboard/COLUMN_1: D1.1 (K), D8.1 (K), D15.1 (K), D21.1 (K), D27.1 (K), D33.1 (K), D39.1 (K), D45.1 (K), U4.17 (PA08)
/Keyboard/COLUMN_2: D2.1 (K), D9.1 (K), D16.1 (K), D22.1 (K), D28.1 (K), D34.1 (K), D40.1 (K), D46.1 (K), U4.18 (PA09)
/Keyboard/COLUMN_3: D3.1 (K), D10.1 (K), D17.1 (K), D23.1 (K), D29.1 (K), D35.1 (K), D41.1 (K), D47.1 (K), U4.19 (PA10)
/Keyboard/COLUMN_4: D4.1 (K), D11.1 (K), D18.1 (K), D24.1 (K), D30.1 (K), D36.1 (K), D42.1 (K), D48.1 (K), U4.20 (PA11)
/Keyboard/COLUMN_5: D5.1 (K), D12.1 (K), D19.1 (K), D25.1 (K), D31.1 (K), D37.1 (K), D43.1 (K), D49.1 (K), U4.29 (PA12)
/Keyboard/COLUMN_6: D6.1 (K), D13.1 (K), D20.1 (K), D26.1 (K), D32.1 (K), D38.1 (K), D44.1 (K), D50.1 (K), U4.30 (PA13)
/Keyboard/COLUMN_7: D7.1 (K), D14.1 (K), U4.31 (PA14)
/Keyboard/COLUMN_8: U4.32 (PA15)
/Keyboard/ROW_1: SW2.2, SW3.2, SW4.2, SW5.2, SW6.2, SW7.2, SW8.2, U4.1 (PA00)
/Keyboard/ROW_2: SW9.2, SW10.2, SW11.2, SW12.2, SW13.2, SW14.2, SW15.2, U4.2 (PA01)
/Keyboard/ROW_3: SW16.2, SW17.2, SW18.2, SW19.2, SW20.2, SW21.2, U4.3 (PA02)
/Keyboard/ROW_4: SW22.2, SW23.2, SW24.2, SW25.2, SW26.2, SW27.2, U4.4 (PA03)
/Keyboard/ROW_5: SW28.2, SW29.2, SW30.2, SW31.2, SW32.2, SW33.2, U4.13 (PA04)
/Keyboard/ROW_6: SW34.2, SW35.2, SW36.2, SW37.2, SW38.2, SW39.2, U4.14 (PA05)
/Keyboard/ROW_7: SW40.2, SW41.2, SW42.2, SW43.2, SW44.2, SW45.2, U4.15 (PA06)
/Keyboard/ROW_8: SW46.2, SW47.2, SW48.2, SW49.2, SW50.2, SW51.2, U4.16 (PA07)
/Keyboard/SWD_CLK: J6.2, R7.2, U4.57 (PA30)
/Keyboard/SWD_IO: J6.3, U4.58 (PA31)
/Keyboard/USB_DM_KEYBOARD: U4.45 (PA24); also elsewhere on the board
/Keyboard/USB_DP_KEYBOARD: U4.46 (PA25); also elsewhere on the board
GND: C22.2, C23.2, C24.2, C25.2, C26.2, C27.2, C28.2, C29.2, J6.4, R8.2, U4.7 (GNDANA), U4.22 (GND), U4.33 (GND), U4.47 (GND), U4.54 (GND); also elsewhere on the board
unnamed: D1.2 (A), SW2.1
unnamed: D2.2 (A), SW3.1
unnamed: D3.2 (A), SW4.1
unnamed: D4.2 (A), SW5.1
unnamed: D5.2 (A), SW6.1
unnamed: D6.2 (A), SW7.1
unnamed: D7.2 (A), SW8.1
unnamed: D8.2 (A), SW9.1
unnamed: D9.2 (A), SW10.1
unnamed: D10.2 (A), SW11.1
unnamed: D11.2 (A), SW12.1
unnamed: D12.2 (A), SW13.1
unnamed: D13.2 (A), SW14.1
unnamed: D14.2 (A), SW15.1
unnamed: D15.2 (A), SW16.1
unnamed: D16.2 (A), SW17.1
unnamed: D17.2 (A), SW18.1
unnamed: D18.2 (A), SW19.1
unnamed: D19.2 (A), SW20.1
unnamed: D20.2 (A), SW21.1
unnamed: D21.2 (A), SW22.1
unnamed: D22.2 (A), SW23.1
unnamed: D23.2 (A), SW24.1
unnamed: D24.2 (A), SW25.1
unnamed: D25.2 (A), SW26.1
unnamed: D26.2 (A), SW27.1
unnamed: D27.2 (A), SW28.1
unnamed: D28.2 (A), SW29.1
unnamed: D29.2 (A), SW30.1
unnamed: D30.2 (A), SW31.1
unnamed: D31.2 (A), SW32.1
unnamed: D32.2 (A), SW33.1
unnamed: D33.2 (A), SW34.1
unnamed: D34.2 (A), SW35.1
unnamed: D35.2 (A), SW36.1
unnamed: D36.2 (A), SW37.1
unnamed: D37.2 (A), SW38.1
unnamed: D38.2 (A), SW39.1
unnamed: D39.2 (A), SW40.1
unnamed: D40.2 (A), SW41.1
unnamed: D41.2 (A), SW42.1
unnamed: D42.2 (A), SW43.1
unnamed: D43.2 (A), SW44.1
unnamed: D44.2 (A), SW45.1
unnamed: D45.2 (A), SW46.1
unnamed: D46.2 (A), SW47.1
unnamed: D47.2 (A), SW48.1
unnamed: D48.2 (A), SW49.1
unnamed: D49.2 (A), SW50.1
unnamed: D50.2 (A), SW51.1
unnamed: R6.2, U4.52 (~RESET)
unnamed: R8.1, SW52.1 (A), U4.50 (PB23)
unnamed: R9.1, SW52.2 (B)

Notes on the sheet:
Game mode toggle switch

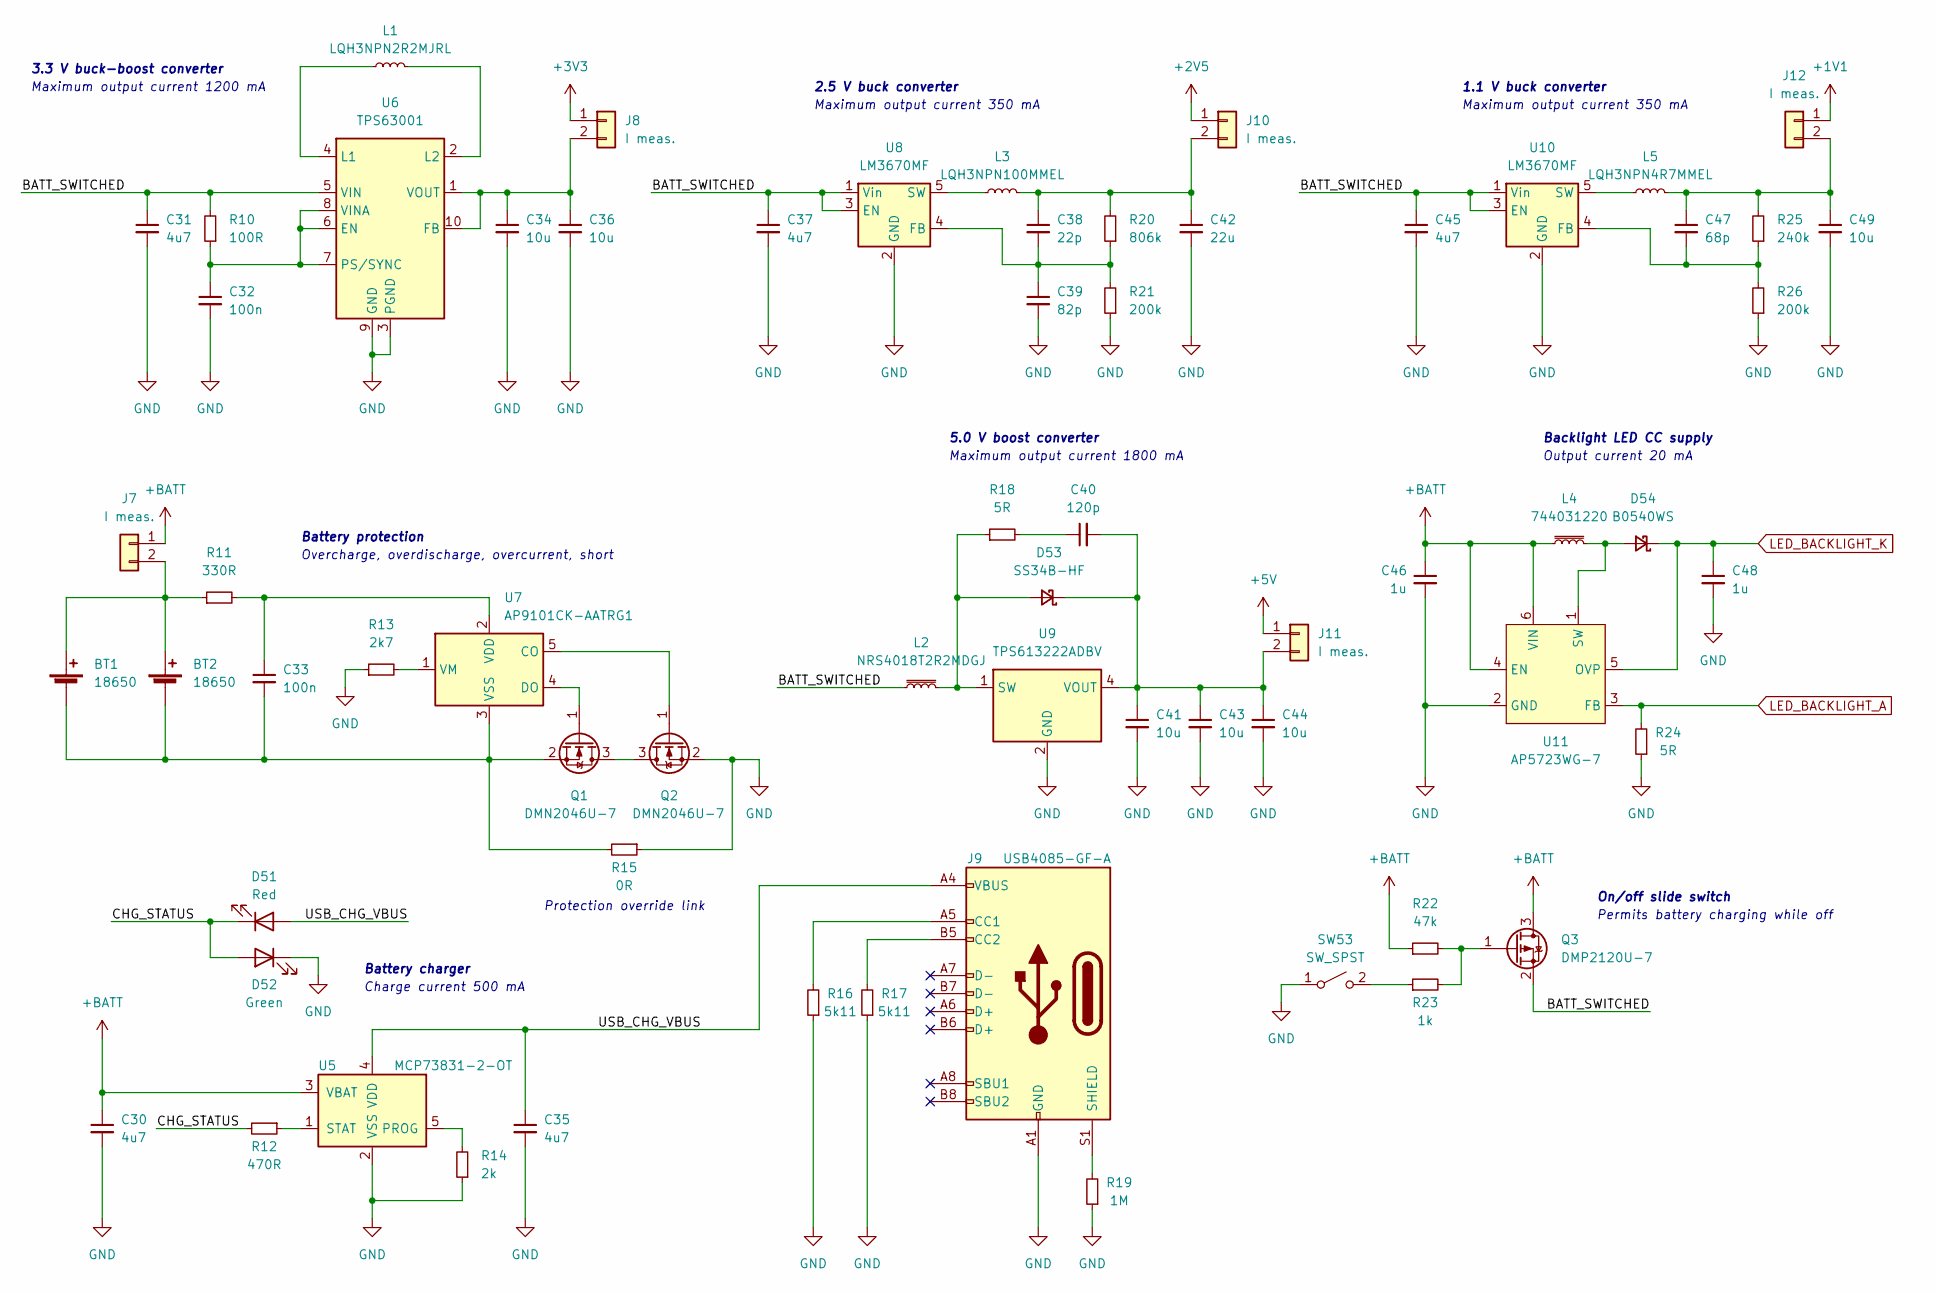
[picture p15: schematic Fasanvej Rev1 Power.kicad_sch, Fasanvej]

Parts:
BT1, BT2: 18650; BatteryHolder_Keystone_1042_1x18650
C30, C31, C35, C37, C45: 4u7; C_1206_3216Metric_Pad1.33x1.80mm_HandSolder
C32, C33: 100n; C_0603_1608Metric_Pad1.08x0.95mm_HandSolder
C34, C36, C41, C43, C44: 10u; C_1210_3225Metric_Pad1.33x2.70mm_HandSolder
C38: 22p; C_0603_1608Metric_Pad1.08x0.95mm_HandSolder
C39: 82p; C_0603_1608Metric_Pad1.08x0.95mm_HandSolder
C40: 120p; C_0603_1608Metric_Pad1.08x0.95mm_HandSolder
C42: 22u; C_1210_3225Metric_Pad1.33x2.70mm_HandSolder
C46, C48: 1u; C_0805_2012Metric_Pad1.18x1.45mm_HandSolder
C47: 68p; C_0603_1608Metric_Pad1.08x0.95mm_HandSolder
C49: 10u; C_1206_3216Metric_Pad1.33x1.80mm_HandSolder
D51: Red; LED_0805_2012Metric_Pad1.15x1.40mm_HandSolder
D52: Green; LED_0805_2012Metric_Pad1.15x1.40mm_HandSolder
D53: SS34B-HF; D_SMB_Handsoldering
D54: B0540WS; D_SOD-323_HandSoldering
J7, J8, J10, J11, J12: I meas.; PinHeader_1x02_P2.54mm_Vertical
J9: USB4085-GF-A; USB_C_Receptacle_GCT_USB4085
L1: LQH3NPN2R2MJRL; L_SMD_3030
L2: NRS4018T2R2MDGJ; L_Taiyo-Yuden_NR-40xx_HandSoldering
L3: LQH3NPN100MMEL; L_SMD_3030
L4: 744031220; L_Wuerth_WE-TPC-3816
L5: LQH3NPN4R7MMEL; L_SMD_3030
Q1, Q2: DMN2046U-7; SOT-23_Handsoldering
Q3: DMP2120U-7; SOT-23_Handsoldering
R10: 100R; R_0603_1608Metric_Pad0.98x0.95mm_HandSolder
R11: 330R; R_1206_3216Metric_Pad1.30x1.75mm_HandSolder
R12: 470R; R_0603_1608Metric_Pad0.98x0.95mm_HandSolder
R13: 2k7; R_1206_3216Metric_Pad1.30x1.75mm_HandSolder
R14: 2k; R_0603_1608Metric_Pad0.98x0.95mm_HandSolder
R15: 0R; R_1210_3225Metric_Pad1.30x2.65mm_HandSolder
R16, R17: 5k11; R_0603_1608Metric_Pad0.98x0.95mm_HandSolder
R18: 5R; R_0603_1608Metric_Pad0.98x0.95mm_HandSolder
R19: 1M; R_0603_1608Metric_Pad0.98x0.95mm_HandSolder
R20: 806k; R_0603_1608Metric_Pad0.98x0.95mm_HandSolder
R21, R26: 200k; R_0603_1608Metric_Pad0.98x0.95mm_HandSolder
R22: 47k; R_0603_1608Metric_Pad0.98x0.95mm_HandSolder
R23: 1k; R_0603_1608Metric_Pad0.98x0.95mm_HandSolder
R24: 5R; R_1210_3225Metric_Pad1.30x2.65mm_HandSolder
R25: 240k; R_0603_1608Metric_Pad0.98x0.95mm_HandSolder
SW53: SW_SPST; SW_CuK_JS202011AQN_DPDT_Angled
U5: MCP73831-2-OT; SOT-23-5
U6: TPS63001; Texas_DRC0010J_ThermalVias
U7: AP9101CK-AATRG1; SOT-23-5
U8, U10: LM3670MF; TSOT-23-5
U9: TPS613222ADBV; SOT-23-5
U11: AP5723WG-7; SOT-23-6_Handsoldering

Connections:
+1V1: J12.1; also elsewhere on the board
+2V5: J10.1; also elsewhere on the board
+3V3: J8.1; also elsewhere on the board
+5V: J11.1; also elsewhere on the board
+BATT: C30.1, C46.1, J7.1, L4.1, Q3.3 (D), R22.1, U5.3 (VBAT), U11.4 (EN), U11.6 (VIN)
/Power/BATT_SWITCHED: C31.1, C37.1, C45.1, L2.1, Q3.2 (S), R10.2, U6.5 (VIN), U8.1 (Vin), U8.3 (EN), U10.1 (Vin), U10.3 (EN)
/Power/CHG_STATUS: D51.1 (K), D52.2 (A), R12.2
/Power/USB_CHG_VBUS: C35.1, D51.2 (A), J9.A4 (VBUS), J9.A9 (VBUS), J9.B4 (VBUS), J9.B9 (VBUS), U5.4 (VDD)
GND: C30.2, C31.2, C32.2, C34.2, C35.2, C36.2, C37.2, C39.2, C41.2, C42.2, C43.2, C44.2, C45.2, C46.2, C48.2, C49.2, D52.1 (K), J9.A1 (GND), J9.A12 (GND), J9.B1 (GND), J9.B12 (GND), Q2.2 (S), R13.1, R14.1, R15.1, R16.1, R17.1, R19.1, R21.1, R24.1, R26.1, SW53.1 (A), U5.2 (VSS), U6.3 (PGND), U6.9 (GND), U6.11 (PGND), U8.2 (GND), U9.2 (GND), U10.2 (GND), U11.2 (GND); also elsewhere on the board
LED_BACKLIGHT_A: R24.2, U11.3 (FB); also elsewhere on the board
LED_BACKLIGHT_K: C48.1, D54.1 (K), U11.5 (OVP); also elsewhere on the board
unnamed: BT1.1 (+), BT2.1 (+), J7.2, R11.1
unnamed: BT1.2 (-), BT2.2 (-), C33.2, Q1.2 (S), R15.2, U7.3 (VSS)
unnamed: C32.1, R10.1, U6.6 (EN), U6.7 (PS/SYNC), U6.8 (VINA)
unnamed: C33.1, R11.2, U7.2 (VDD)
unnamed: C34.1, C36.1, J8.2, U6.1 (VOUT), U6.10 (FB)
unnamed: C38.1, C42.1, J10.2, L3.2, R20.2
unnamed: C38.2, C39.1, R20.1, R21.2, U8.4 (FB)
unnamed: C40.1, R18.2
unnamed: C40.2, C41.1, C43.1, C44.1, D53.1 (K), J11.2, U9.4 (VOUT)
unnamed: C47.1, C49.1, J12.2, L5.2, R25.2
unnamed: C47.2, R25.1, R26.2, U10.4 (FB)
unnamed: D53.2 (A), L2.2, R18.1, U9.1 (SW)
unnamed: D54.2 (A), L4.2, U11.1 (SW)
unnamed: J9.A5 (CC1), R16.2
unnamed: J9.B5 (CC2), R17.2
unnamed: J9.S1 (SHIELD), R19.2
unnamed: L1.1, U6.4 (L1)
unnamed: L1.2, U6.2 (L2)
unnamed: L3.1, U8.5 (SW)
unnamed: L5.1, U10.5 (SW)
unnamed: Q1.1 (G), U7.4 (DO)
unnamed: Q1.3 (D), Q2.3 (D)
unnamed: Q2.1 (G), U7.5 (CO)
unnamed: Q3.1 (G), R22.2, R23.2
unnamed: R12.1, U5.1 (STAT)
unnamed: R13.2, U7.1 (VM)
unnamed: R14.2, U5.5 (PROG)
unnamed: R23.1, SW53.2 (B)

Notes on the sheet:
Maximum output current 350 mA
Output current 20 mA
Permits battery charging while off
Charge current 500 mA
Protection override link
Battery charger
3.3 V buck-boost converter
Overcharge, overdischarge, overcurrent, short
Backlight LED CC supply
1.1 V buck converter
5.0 V boost converter
Maximum output current 1200 mA
2.5 V buck converter
Maximum output current 1800 mA
On/off slide switch
Battery protection

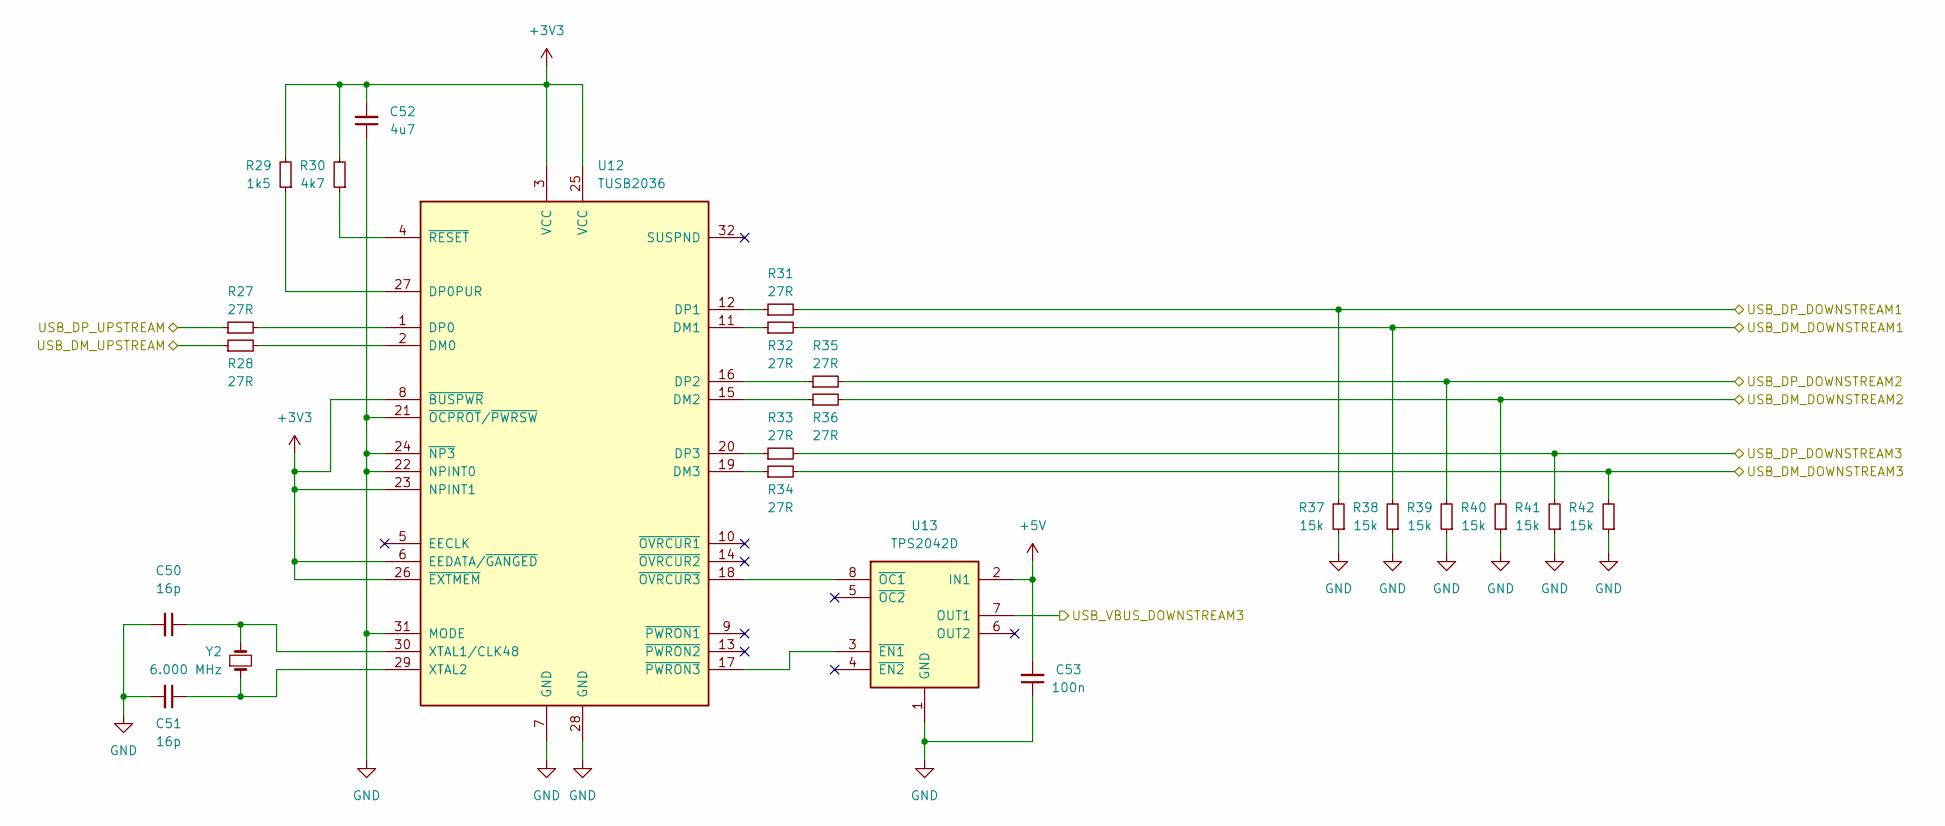
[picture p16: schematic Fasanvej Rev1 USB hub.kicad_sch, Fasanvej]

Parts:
C50, C51: 16p; C_0603_1608Metric_Pad1.08x0.95mm_HandSolder
C52: 4u7; C_1206_3216Metric_Pad1.33x1.80mm_HandSolder
C53: 100n; C_0603_1608Metric_Pad1.08x0.95mm_HandSolder
R27, R28, R31, R32, R33, R34, R35, R36: 27R; R_0603_1608Metric_Pad0.98x0.95mm_HandSolder
R29: 1k5; R_0603_1608Metric_Pad0.98x0.95mm_HandSolder
R30: 4k7; R_0603_1608Metric_Pad0.98x0.95mm_HandSolder
R37, R38, R39, R40, R41, R42: 15k; R_0603_1608Metric_Pad0.98x0.95mm_HandSolder
U12: TUSB2036; LQFP-32_7x7mm_P0.8mm
U13: TPS2042D; SOIC-8_3.9x4.9mm_P1.27mm
Y2: 6.000 MHz; Crystal_SMD_HC49-SD_HandSoldering

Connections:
+3V3: C52.2, R29.2, R30.2, U12.3 (VCC), U12.6 (EEDATA/~GANGED), U12.8 (~BUSPWR), U12.23 (NPINT1), U12.25 (VCC), U12.26 (~EXTMEM); also elsewhere on the board
+5V: C53.2, U13.2 (IN1); also elsewhere on the board
/Keyboard/USB_DM_KEYBOARD: R32.2, R38.2; also elsewhere on the board
/Keyboard/USB_DP_KEYBOARD: R31.2, R37.2; also elsewhere on the board
/USB_DM_EXTERNAL: R34.2, R42.2; also elsewhere on the board
/USB_DM_HOST: R28.1; also elsewhere on the board
/USB_DM_WIFI: R36.2, R40.2; also elsewhere on the board
/USB_DP_EXTERNAL: R33.2, R41.2; also elsewhere on the board
/USB_DP_HOST: R27.1; also elsewhere on the board
/USB_DP_WIFI: R35.2, R39.2; also elsewhere on the board
/USB_VBUS_EXTERNAL: U13.7 (OUT1); also elsewhere on the board
GND: C50.2, C51.2, C52.1, C53.1, R37.1, R38.1, R39.1, R40.1, R41.1, R42.1, U12.7 (GND), U12.21 (~OCPROT/~PWRSW), U12.22 (NPINT0), U12.24 (~NP3), U12.28 (GND), U12.31 (MODE), U13.1 (GND); also elsewhere on the board
unnamed: C50.1, U12.30 (XTAL1/CLK48), Y2.2
unnamed: C51.1, U12.29 (XTAL2), Y2.1
unnamed: R27.2, U12.1 (DP0)
unnamed: R28.2, U12.2 (DM0)
unnamed: R29.1, U12.27 (DP0PUR)
unnamed: R30.1, U12.4 (~RESET)
unnamed: R31.1, U12.12 (DP1)
unnamed: R32.1, U12.11 (DM1)
unnamed: R33.1, U12.20 (DP3)
unnamed: R34.1, U12.19 (DM3)
unnamed: R35.1, U12.16 (DP2)
unnamed: R36.1, U12.15 (DM2)
unnamed: U12.17 (~PWRON3), U13.3 (~EN1)
unnamed: U12.18 (~OVRCUR3), U13.8 (~OC1)

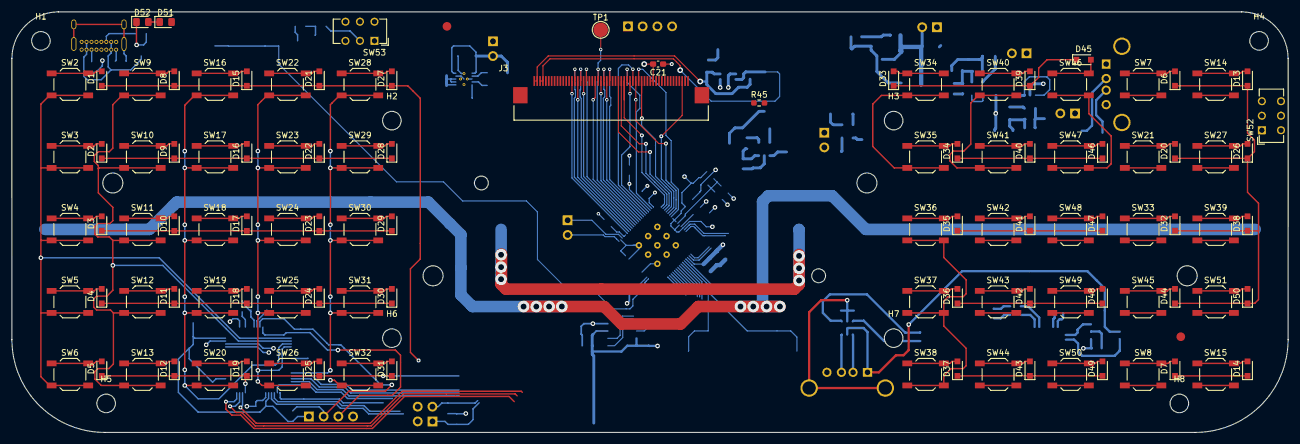
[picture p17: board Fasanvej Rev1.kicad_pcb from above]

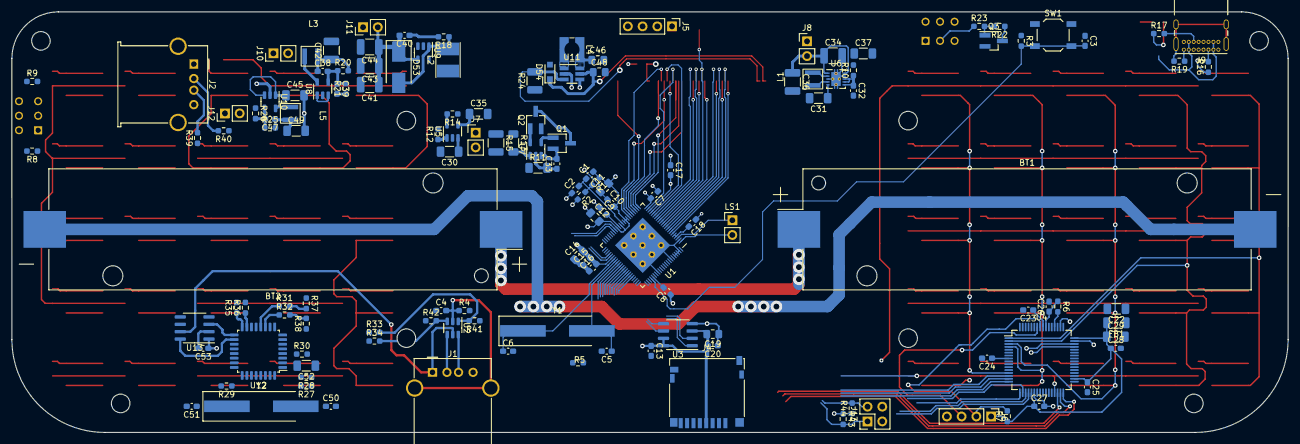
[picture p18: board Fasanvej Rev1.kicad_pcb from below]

Board: 2 copper layers, 220.0 x 72.5 mm, 256 parts (138 on the bottom side), 181 nets.

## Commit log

2022-02-17 Added SPI NOR FLASH. Finished power connections to SoC. Added SWD for keyboard MCU. Improved USB ESD protection. Finished all SoC connections. Added DDR VREF divider.
    [Fasanvej Rev1 Keyboard.kicad_sch, Fasanvej Rev1.kicad_sch]
2022-02-21 Finished schematics. Pending validation.
    [Fasanvej Rev1 Keyboard.kicad_sch, Fasanvej Rev1 Power.kicad_sch, Fasanvej Rev1.kicad_sch]
2022-02-22 Finalized schematics some more. Still missing a few footprints.
    [Fasanvej Rev1 Keyboard.kicad_sch, Fasanvej Rev1 Power.kicad_sch, Fasanvej Rev1.kicad_sch]
2022-02-24 Schematic finalized. Started PCB layout.
    [Fasanvej Rev1 Power.kicad_sch, Fasanvej Rev1 USB hub.kicad_sch, Fasanvej Rev1.kicad_pcb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]
2022-02-24 Started placing components
    [Fasanvej Rev1.kicad_pcb]
2022-02-27 Made a lot of progress laying out PCB
    [Fasanvej Rev1 Keyboard.kicad_sch, Fasanvej Rev1 Power.kicad_sch, Fasanvej Rev1 USB hub.kicad_sch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]
2022-03-02 Made progress with board layout as well as mechanical (case) design
    [Fasanvej Rev1.kicad_pcb, Fasanvej Rev1.kicad_sch]
2022-03-04 Made progress with PCB layout. Preliminary case design added.
    [5x5 keymap.STL, Case bottom.STL, Case top.STL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]
